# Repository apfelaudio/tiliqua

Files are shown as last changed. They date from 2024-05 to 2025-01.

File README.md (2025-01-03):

# Tiliqua

<sup>WARN: 🚧 under construction! 🚧 - this module is in active development</sup>

**Tiliqua is a powerful, open hardware FPGA-based audio multitool for Eurorack.**

For updates, join the [matrix chatroom](https://matrix.to/#/#apfaudio:matrix.org), subscribe to the [Crowd Supply page](https://www.crowdsupply.com/apfaudio/tiliqua) or my own [mailing list](https://apf.audio/)

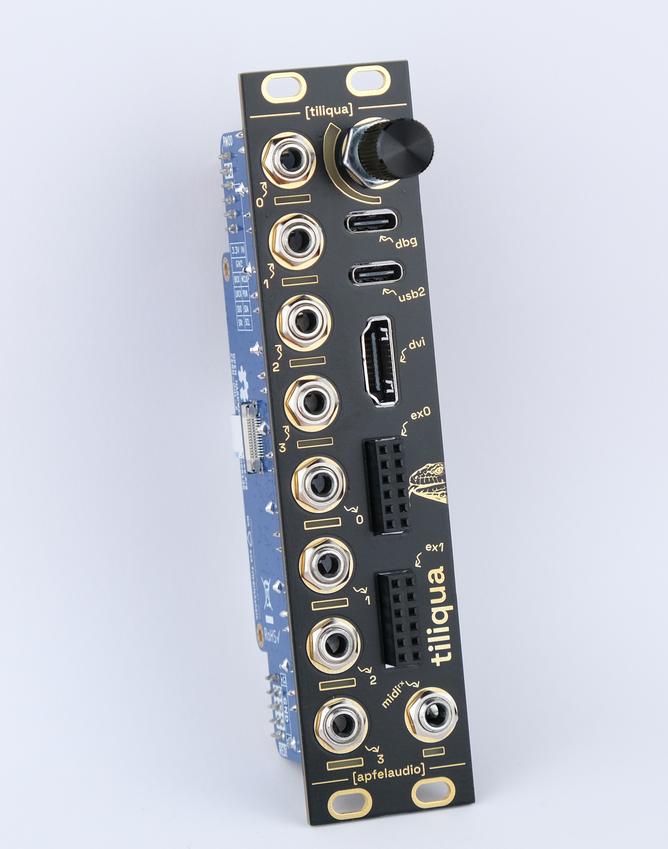
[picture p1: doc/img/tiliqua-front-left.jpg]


# Documentation

Available at [apfaudio.github.io/tiliqua](https://apfaudio.github.io/tiliqua/) (🚧 under construction)

Documentation is built from source in `gateware/docs`.

# Community

`apfaudio` has a Matrix channel, [#apfaudio:matrix.org](https://matrix.to/#/#apfaudio:matrix.org). Feel free to join to ask questions or discuss ongoing development.

Participants in this project are expected to adhere to the [Berlin Code of Conduct](https://berlincodeofconduct.org/).

## Builds on the following (awesome) open projects

- The [Amaranth HDL](https://github.com/amaranth-lang/amaranth) and [Amaranth SoC](https://github.com/amaranth-lang/amaranth-soc) projects.
- Audio interface and gateware from my existing [eurorack-pmod](https://github.com/apfaudio/eurorack-pmod) project.
- USB interface and gateware based on [LUNA and Cynthion](https://github.com/greatscottgadgets/luna/) projects.
- USB Audio gateware and descriptors based on [adat-usb2-audio-interface](https://github.com/hansfbaier/adat-usb2-audio-interface).
- Some gateware is also inherited from the [Glasgow](https://github.com/GlasgowEmbedded/glasgow) project.

# License

The hardware and gateware in this project is largely covered under the CERN Open-Hardware License V2 CERN-OHL-S, mirrored in the LICENSE text in this repository. Some gateware and software is covered under the BSD 3-clause license - check the header of the individual source files for specifics.

**Copyright (C) 2024 Sebastian Holzapfel**

The above LICENSE and copyright notice do NOT apply to imported artifacts in this repository (i.e datasheets, third-party footprints), or dependencies released under a different (but compatible) open-source license.

# Derivative works

As an addendum to the above license: if you create or manufacture your own derivative hardware, the name `apf.audio`, the names of any `apf.audio` products and the names of the authors, are *not to be used in derivative hardware or marketing materials*, except where obligated for attribution and for retaining the above copyright notice.

For example, your 3U adaptation of "apf.audio Tiliqua" could be called "Gizzard Modular - Lizardbobulator".

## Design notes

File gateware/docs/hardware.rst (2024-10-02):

Hardware overview
#################

Front
-----

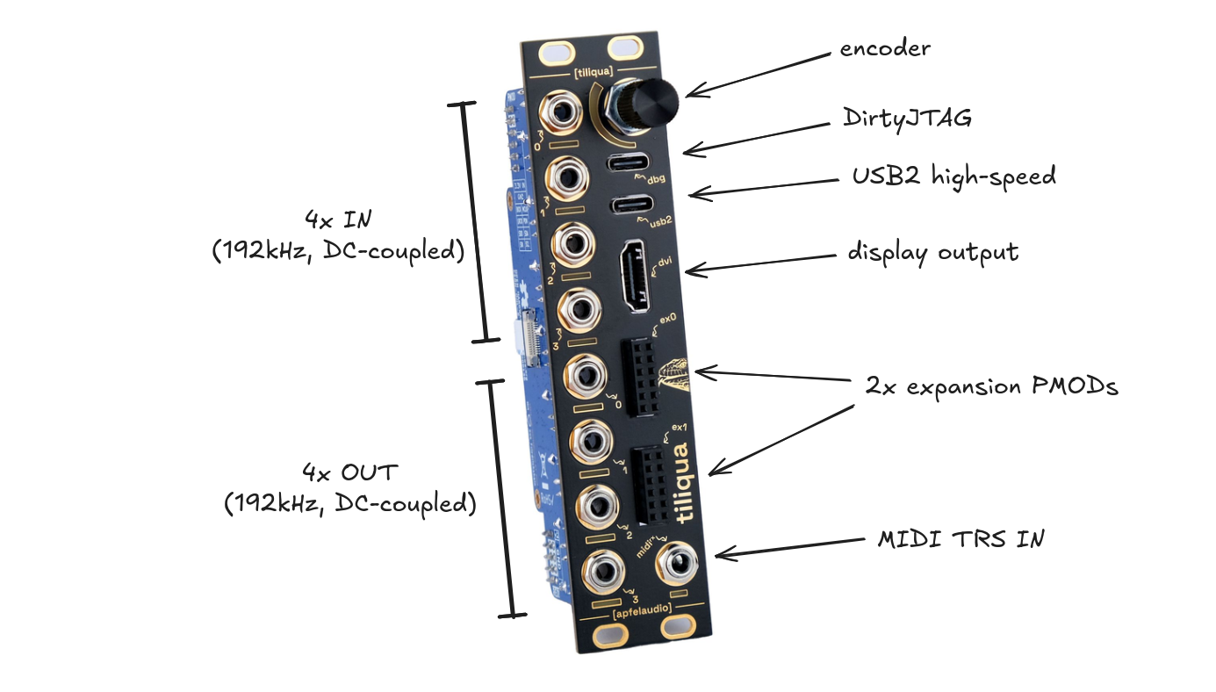
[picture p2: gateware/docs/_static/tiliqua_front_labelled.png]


Back
----

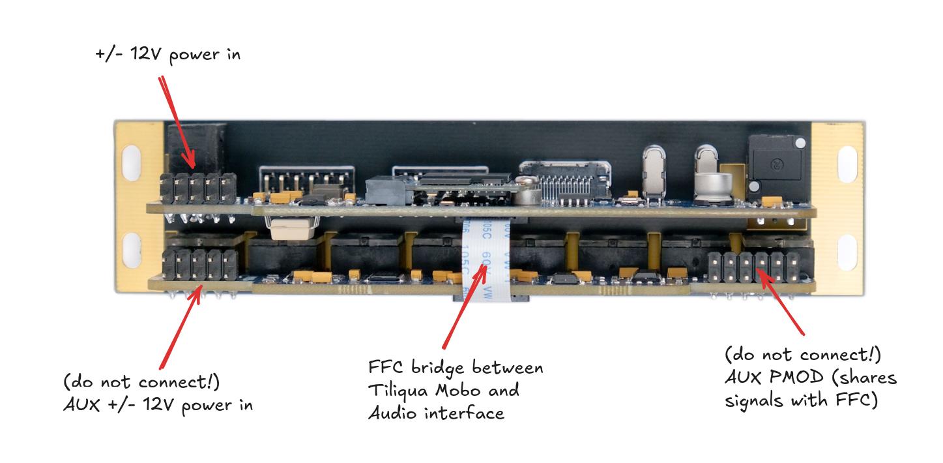
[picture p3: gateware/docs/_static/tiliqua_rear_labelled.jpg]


Power ingress
-------------

.. warning::

    Tiliqua uses an ordinary 10-pin power cable for +/- 12V ingress. You will notice however, that there are 2 such connectors on the module. **Only ONE of these should be connected**:

    - Use the 10-pin power ingress on the Tiliqua Motherboard, not the Audio Interface Board. Technically both will work, but only the former is fused (on beta R2 units).
    - Both connectors on the audio interface board (eurorack-pmod) should remain unconnected.
    - Make sure the red stripe on the IDC cable is aligned with the RED marker on the PCB.

Debug USB port
--------------

For flashing bitstreams, usually you want to be connected to the dbg USB port. This is directly connected to the on-board RP2040 which is flashed with dirtyJtag, such that you can flash bitstreams using openFPGALoader.

Audio jacks
-----------

Particularly for bitstreams with touch sensing, ensure all jacks are disconnected when the tiliqua is powered on. This is because the capacitive sensing is calibrated when the system boots. In the future I'll change this to happen every time something is dis/re-connected.

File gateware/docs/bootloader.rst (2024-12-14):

Bootloader
##########

.. note::

    'Bootloader' is a bit of a misnomer, as what is currently implemented is more like a 'bitstream selector' (although a true USB bootloader is something in the works).

Interface
---------

The bitstream selector allows you to arbitrarily select from one of 8 bitstreams after the Tiliqua powers on, without needing to connect a computer.

Put simply:

- When tiliqua boots, you can select a bitstream with the encoder (either using the display output, or by reading the currently lit LED if no display is connected).
- When you select a bitstream (press encoder), the FPGA reconfigures itself and enters the selected bitstream.
- From the new bitstream, you can always go back to the bitstream selector by holding the encoder for 3sec (this is built into the logic of every bitstream).

.. warning::

    The bitstream selector will not reboot correctly if you have
    the :py:`dbg` USB port connected. The assumption is you're flashing
    development bitstreams to SRAM in that scenario anyway.

Setup and implementation
------------------------

The bitstream selector consists of 2 key components that work together:

- The RP2040 firmware (`apfelbug - fork of dirtyJTAG <https://github.com/apfaudio/apfelbug>`_)
- The `bootloader <https://github.com/apfaudio/tiliqua/tree/main/gateware/src/top/bootloader>`_ top-level bitstream.

The difficulty here is that the ECP5 multiboot mechanism only supports rebooting from one bitstream to a single fixed new address :code:`bootaddr`, which is not sufficient for arbitrary bitstream selection. It would in theory have been possible to set up a 'bitstream chain', however that would require all bitstreams to be correctly flashed with the correct addresses at all times, which is not ideal for development. So, the solution here is more complicated, but hopefully more robust to 'less trustworthy' bitstreams.

First-time setup
^^^^^^^^^^^^^^^^

- Build and flash the `apfelbug <https://github.com/apfaudio/apfelbug>`_ project to the RP2040 (hold RP2040 BOOTSEL during power on, copy the :code:`build/*.uf2` to the usb storage device and reset)
- On the Tiliqua ECP5 SPI flash:
    - Using :code:`openFPGALoader -c dirtyJtag <bitstream> -f o <offset>`
    - flash :code:`bootloader` bitstream to offset 0x0
    - flash user bitstreams to 0x100000, 0x200000, 0x300000 ... and so on (1MB spacing)
- DISCONNECT USB DBG port, reboot Tiliqua
    - Currently :code:`apfelbug` only works correctly with the DBG connector DISCONNECTED or with the UART port open on Linux and CONNECTED. Do not have the USB DBG connected without the UART0 open with :code:`picocom` or so.
- Now when Tiliqua boots you will enter the bootloader. Use the encoder to select an image. Hold the encoder for >3sec in any image to go back to the bootloader.

Bitstream Manifest
^^^^^^^^^^^^^^^^^^

By default the bootloader screen will report all bitstream names as :code:`<unknown>`. The :code:`bootloader` bitstream can optionally read from a JSON manifest stored at the end of SPI flash called a 'Bitstream Manifest'. Such a :code:`manifest.json` file can be copied from :code:`gateware/src/top/bootloader/fw/example-manifest.json`. You can flash this to the end of the SPI flash so the bootloader knows what each bitstream should be called.

.. code-block:: bash

    sudo openFPGALoader -c dirtyJtag -f -o 0xfff000 --file-type raw manifest.json

Note: this address :code:`0xfff000` comes from :code:`src/tiliqua/tiliqua_soc.py`.

Assuming the bootloader bitstream is correctly already flashed to 0x0, this command will also reset the FPGA, re-enter the bootloader, and display the updated bitstream manifest.

At the moment, the bootloader itself does no verification that there are actually bitstreams flashed to each slot corresponding to the names. If a bitstream is not actually in a designated slot or is corrupt, selecting the bad slot will simply reboot the FPGA and re-enter the bootloader.

ECP5 implementation
^^^^^^^^^^^^^^^^^^^

The ECP5 :code:`bootloader` bitstream does nothing except tell the RP2040 that it wants to be rebooted into a new bitstream (over UART). However, the user bitstreams are responsible for asserting PROGRAMN when the encoder is held, to reconfigure back to the bootloader bitstream.

RP2040 implementation
^^^^^^^^^^^^^^^^^^^^^

:code:`apfelbug` firmware includes the same features as :code:`pico-dirtyjtag` (USB-JTAG and USB-UART bridge), with some additions:

- UART traffic is inspected to look for keywords.
- If a keyword is encountered e.g. :code:`BITSTREAM1`, a pre-recorded JTAG stream stored on the RP2040's SPI flash is decompressed and replayed. The JTAG streams are instances of the `bootstub <https://github.com/apfaudio/tiliqua/blob/main/gateware/src/top/bootstub/top.py>`_ top-level bitstream. These are tiny bitstreams that are programmed directly into SRAM with the target :code:`bootaddr` and PROGRAMN assertion.
- This facilitates ECP5 multiboot (jumping to arbitrary bitstreams) without needing to write to the ECP5's SPI flash and exhausting write cycles.

Recording new JTAG streams for RP2040
^^^^^^^^^^^^^^^^^^^^^^^^^^^^^^^^^^^^^

TODO documentation, not necessary to change this for any ordinary usecase. Update this if needed for SoldierCrab R3.

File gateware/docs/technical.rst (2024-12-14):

Hardware details
################

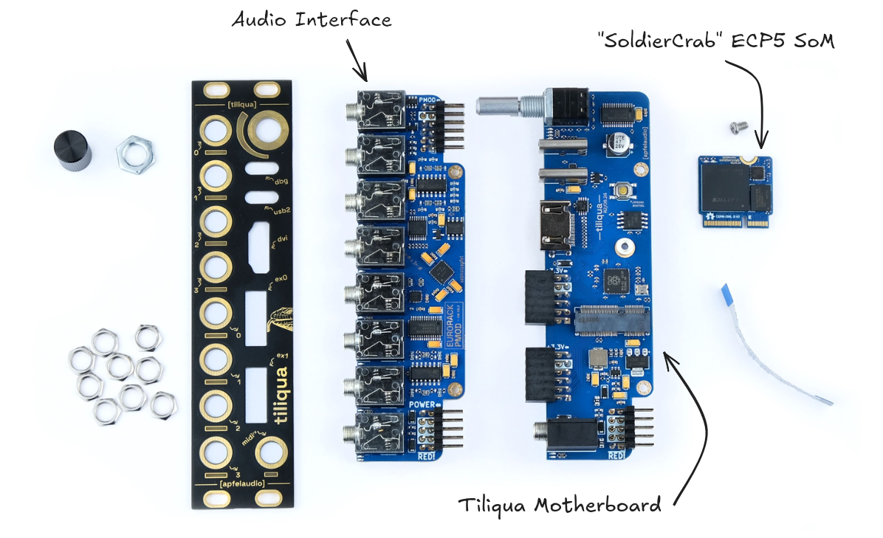
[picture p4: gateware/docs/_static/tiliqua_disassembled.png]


Audio Interface
---------------

**KiCAD files + schematics here:** `eurorack-pmod R3.3 hardware <https://github.com/apfaudio/eurorack-pmod/tree/master/hardware/schematics>`_

- 8 (4 in + 4 out) DC-coupled audio channels, 192 KHz / 24-bit sampling supported
- Touch and proximity sensing on all 8 audio jacks (if unused)
- PWM-controlled, user-programmable red/green LEDs on each audio channel
- Jack insertion detection on all 8 jacks

Motherboard
-----------

**KiCAD files + schematics here:** `Tiliqua R2 motherboard <https://github.com/apfaudio/tiliqua/tree/main/hardware>`_

- Switched rotary encoder with bar graph display.
- Dual USB ports:
    - `dbg`: Included RP2040-based JTAG debugger supported by `openFPGAloader`
    - `usb2`: USB PHY connected directly to FPGA for high-speed USB Audio support
- Display output for video synthesis (maximum resolution 720/60P)
- 2x expansion ports for up to 24 simultaneous audio channels (PMOD-compatible)
- MIDI-In jack (TRS-A standard)

Embedded FPGA SoM (`soldiercrab`)
---------------------------------

**Schematics here :** `SoldierCrab R2 <https://github.com/apfaudio/tiliqua/tree/main/hardware/schematics>`_

.. note::

    SoldierCrab KiCAD files need some cleanup and will be published before the
    CrowdSupply campaign is launched.

- Lattice ECP5 (25 K) FPGA, supported by open-source FPGA toolchains
- 256 Mbit (32 MByte) HyperRAM / oSPI RAM (for long audio buffers or video framebuffers)
- 128 Mbit (16 MByte) SPI flash for user bitstreams
- High-speed USB HS PHY (ULPI)

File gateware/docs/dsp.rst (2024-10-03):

Tiliqua DSP Library
###################

Overview
--------

TODO short overview of the DSP library philosophy.

TODO link to Amaranth documentation on streams.

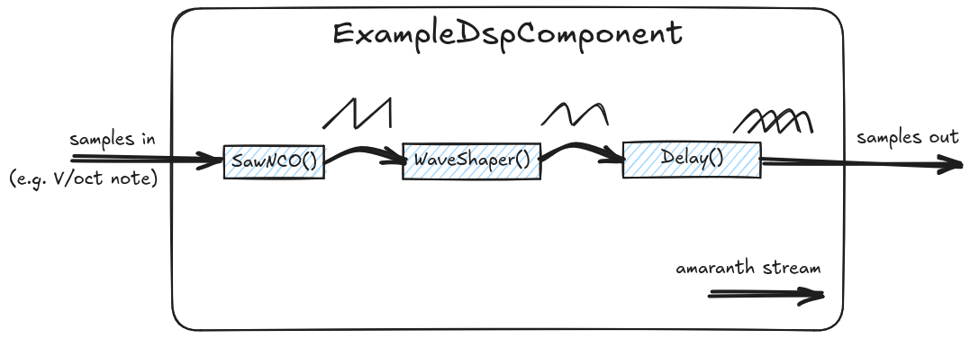
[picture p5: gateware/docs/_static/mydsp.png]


Delay Lines
-----------

.. autoclass:: tiliqua.delay_line.DelayLine
.. autoclass:: tiliqua.delay_line.DelayLineTap

Filters
-------

.. autoclass:: tiliqua.dsp.SVF
.. autoclass:: tiliqua.dsp.FIR
.. autoclass:: tiliqua.dsp.Boxcar

Oscillators
-----------

.. autoclass:: tiliqua.dsp.SawNCO

Effects
-------

.. autoclass:: tiliqua.dsp.WaveShaper
.. autoclass:: tiliqua.dsp.PitchShift

VCAs
----

.. autoclass:: tiliqua.dsp.VCA
.. autoclass:: tiliqua.dsp.GainVCA

Mixing
------

.. autoclass:: tiliqua.dsp.MatrixMix

Resampling
----------

.. autoclass:: tiliqua.dsp.Resample

One-shot
--------

.. autoclass:: tiliqua.dsp.Trigger
.. autoclass:: tiliqua.dsp.Ramp

Stream utilities
----------------

Splitting / merging streams
^^^^^^^^^^^^^^^^^^^^^^^^^^^

.. autoclass:: tiliqua.dsp.Split
.. autoclass:: tiliqua.dsp.Merge

Connecting and remapping streams
^^^^^^^^^^^^^^^^^^^^^^^^^^^^^^^^
.. autofunction:: tiliqua.dsp.connect_remap
.. autofunction:: tiliqua.dsp.channel_remap

Connecting streams in feedback loops
^^^^^^^^^^^^^^^^^^^^^^^^^^^^^^^^^^^^

.. autoclass:: tiliqua.dsp.KickFeedback
.. autofunction:: tiliqua.dsp.connect_feedback_kick

Other utilities
---------------

.. autofunction:: tiliqua.dsp.named_submodules

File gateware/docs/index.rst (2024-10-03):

Tiliqua Manual
##############

.. warning::

   This manual is under construction and very incomplete!



.. toctree::
   :maxdepth: 2

   hardware
   technical
   install
   gettingstarted
   soc
   bootloader
   top
   dsp

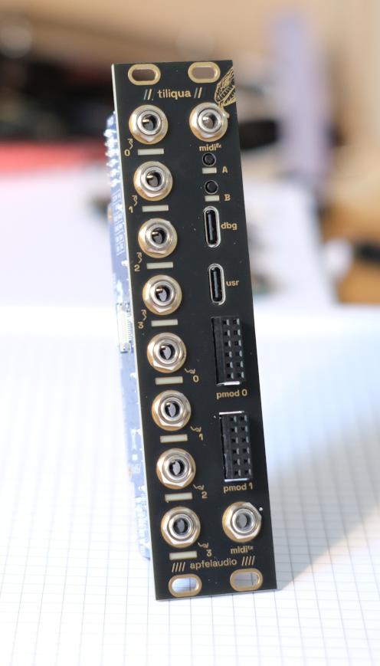
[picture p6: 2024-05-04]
doc/img/tiliqua-proto1-front.jpg

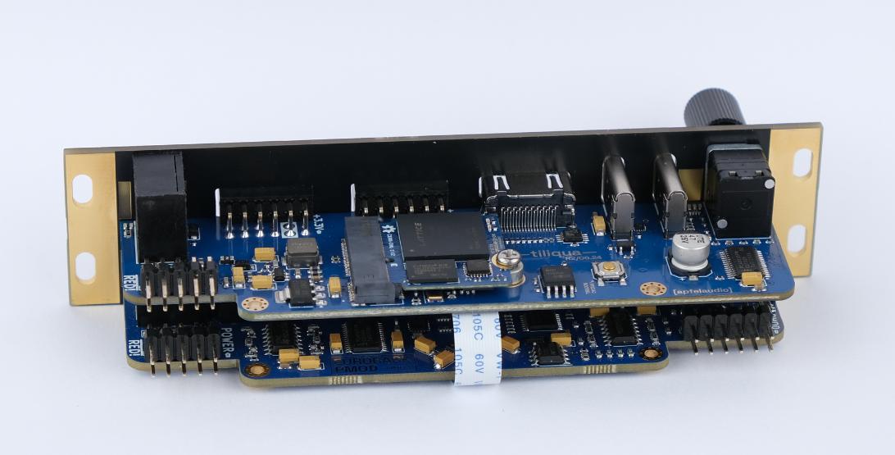
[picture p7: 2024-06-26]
doc/img/tiliqua-rear-left.jpg

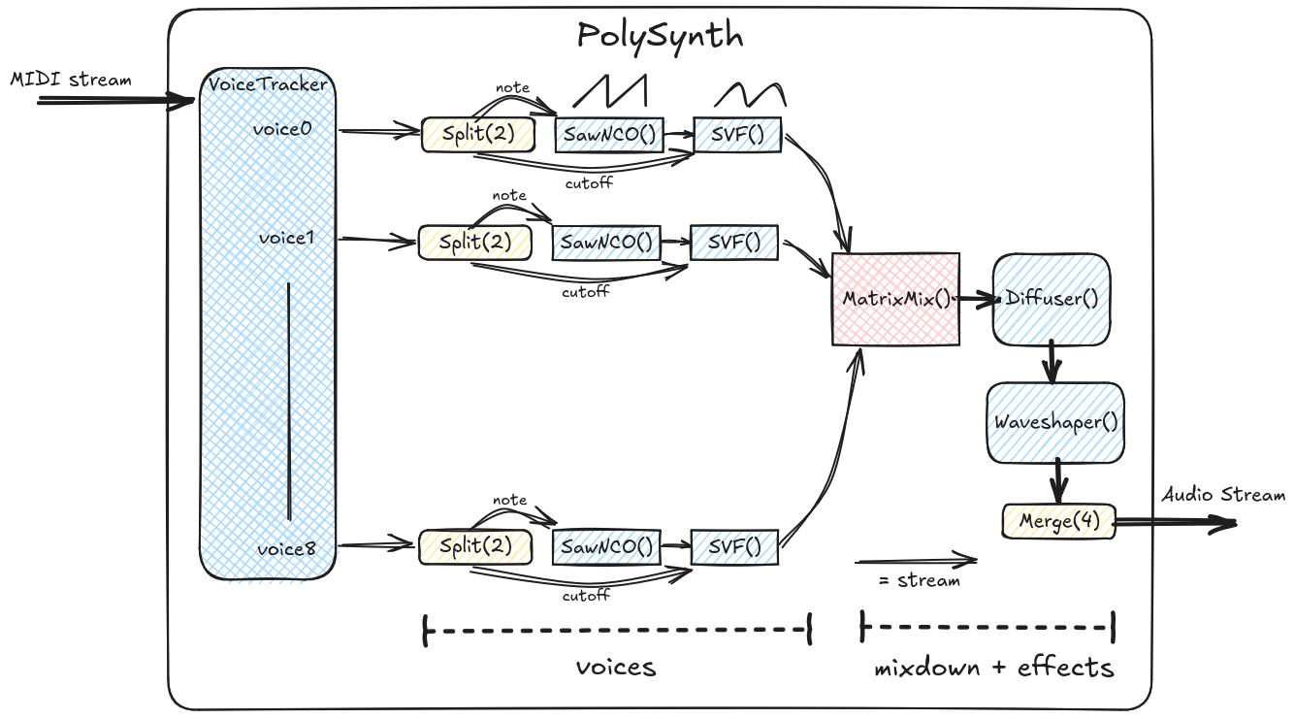
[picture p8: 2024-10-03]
gateware/docs/_static/polysynth.png

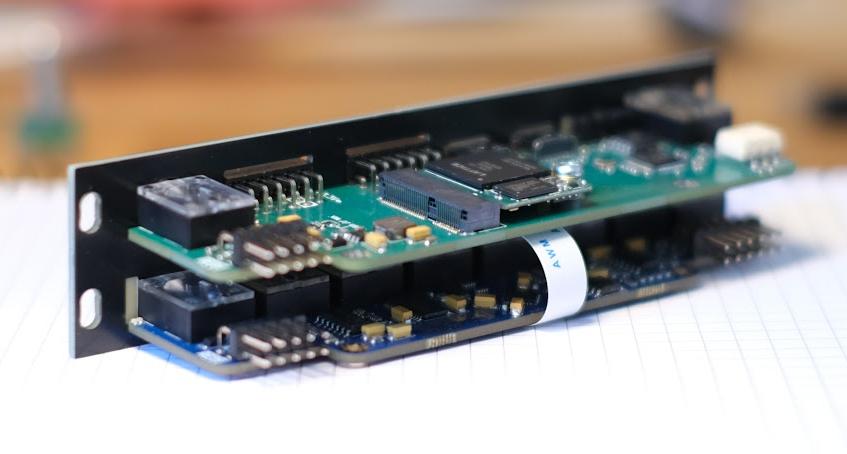
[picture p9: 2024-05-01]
doc/img/tiliqua-proto1-back.jpg

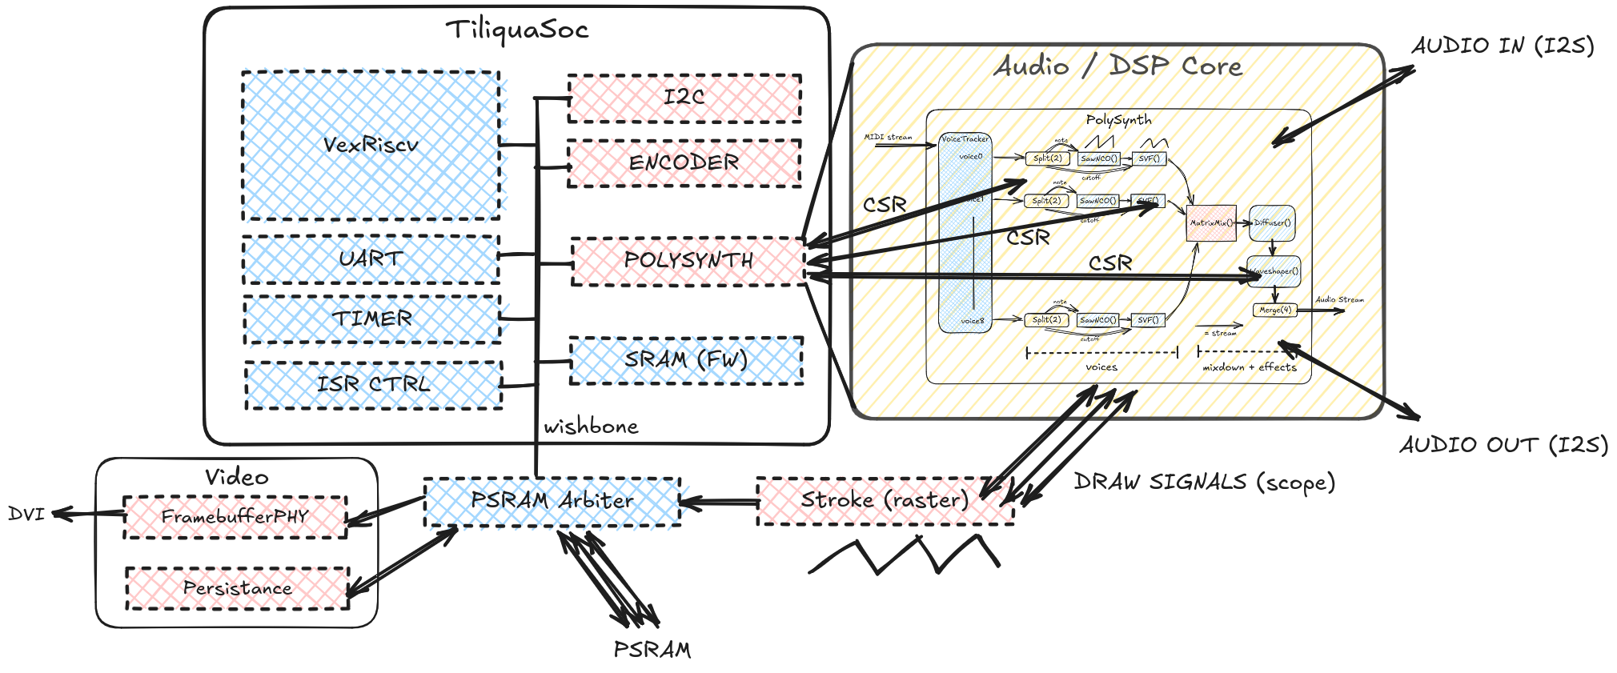
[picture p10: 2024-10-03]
gateware/docs/_static/tiliquasoc.png

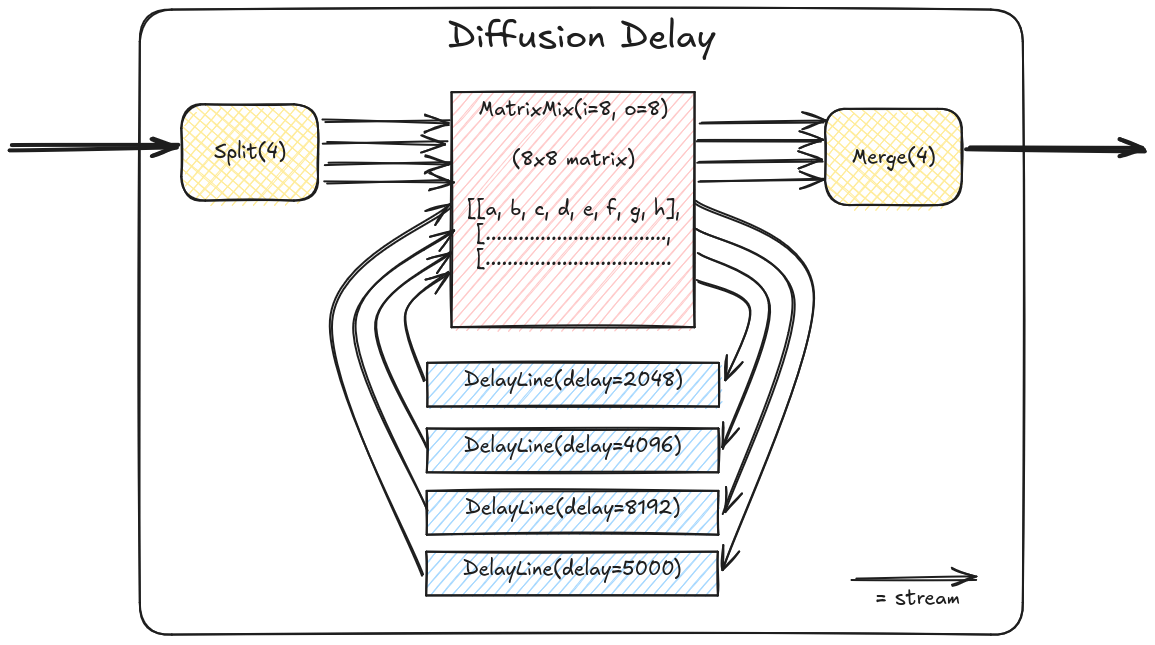
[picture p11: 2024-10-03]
gateware/docs/_static/diffusor.png

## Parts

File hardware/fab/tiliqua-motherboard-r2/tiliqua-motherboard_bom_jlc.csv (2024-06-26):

Comment | Designator | Footprint | LCSC Part #
0.1uF | C1,C2,C3,C4,C5,C6,C7,C8,C9,C10,C13,C14 | C_0402_1005Metric | C307331
2.2uF | C11,C12 | C_0402_1005Metric | C12530
18pF/50V/5%/C0G/C0402 | C15,C16 | C_0402_1005Metric | C1549
22.0uF | C23,C26 | CP_EIA-3216-10_Kemet-I | C782264
100nF | C25,C28,C30,C34,C43,C27 | C_0603_1608Metric | C14663
22uF | C29,C32,C38,C42 | CP_EIA-3216-10_Kemet-I | C782264
100pF | C31 | C_0603_1608Metric | C14858
47uF | C33 | CP_Elec_6.3x5.4 | C88735
10n | C39,C40,C41 | C_0402_1005Metric | C60133
1N4007FL | D1,D2,D3 | D_SOD-123F | C493190
3V6 | D4 | D_SOD-123 | C173412
LED 0402 GREEN | D5,D6,D7,D8,D13,D14,D15,D16 | LED_0402_1005Metric | C2856703
LED 0402 RED | D9,D10,D11,D12,D17,D18,D19,D20 | LED_0402_1005Metric | C965790
15V 200mA | F1,F2 | Fuse_0805_2012Metric | C883103
Conn_01x15 | J1 | FFC_0.5-14P_CTXJ-H2.0_1 | C5378715
Conn_02x06_Top_Bottom | J2,J3 | PinSocket_2x06_P2.54mm_Horizontal | C2897426
~ | J4 | AUDIO-TH_PJ-325M | C2884942
USB_C_Receptacle_USB2.0_14P | J5,J7 | USB-C-TH_U264-141N-4BAC10 | C692526
CONN 2x5 P=2.54mm | J6 | PinHeader_2x05_P2.54mm_Horizontal | C492433
MICROMOD-2222 | J8 | TE_21992304 | C2977809
DVI_GPDI | J10 | HDMI_A_Amphenol_10029449-x01xLF_Horizontal | C428493
FERRITE | L1,L2,L4,L5,L6,L7 | L_0603_1608Metric | C14709
10uH 2A | L3 | L_Vishay_IHLP-2020 | C844996
4K7 | R1,R2,R9,R25,R32 | R_0402_1005Metric | C25900
10K | R3,R4,R23,R13,R14,R21,R22,R29,R30,R27,R33 | R_0402_1005Metric | C25744
100R | R5,R8 | R_0402_1005Metric | C25076
27R | R6,R7 | R_0402_1005Metric | C138021
220R | R10,R16 | R_0402_1005Metric | C25091
5.1K | R11,R12 | R_0402_1005Metric | C25905
1K | R15 | R_0402_1005Metric | C11702
157K (158K) | R17 | R_0402_1005Metric | C861679
30K | R18 | R_0402_1005Metric | C25776
900K (910K) | R20 | R_0402_1005Metric | C25800
18K | R24 | R_0402_1005Metric | C138044
549 | R31 | R_0402_1005Metric | C474081
270 | R34,R35,R36,R37,R38,R39,R40,R41 | R_0402_1005Metric | C25099
120R | RN1,RN2,RN3,RN4 | R_Array_Convex_4x0402 | C326871
SW_Tactile_SPST | SW2 | SW_SPST_SKQG_WithStem | C202424
ZD25WQ16CSIGT(SOIC-8_208mils) | U1 | SOIC-8W_5.3x5.3mm_P1.27mm | C5353597
RP2040(QFN-56_7x7mm_P0.4mm) | U2 | QFN-56-1EP_7x7mm_P0.4mm_EP3.2x3.2mm_ThermalVias | C2040
PCA9306DP | U3 | TSSOP-8_3x3mm_P0.65mm | C128835
H11L1SR2M | U4 | DIP-6_W8.89mm_SMDSocket_LongPads | C20082
AP63200WU | U5 | TSOT-23-6 | C2071868
AMS1117-3.3 | U6 | SOT-223-3_TabPin2 | C347222
PCA9635 LED DRIVER | U7 | TSSOP-28_4.4x9.7mm_P0.65mm | C110795
TUSB322I | U8 | Texas_X2QFN-12_1.6x1.6mm_P0.4mm | C2674422
AP2161W | U9 | SOT-23-5 | C176957
Crystal_GND24_Small | Y1 | Crystal_SMD_3225-4Pin_3.2x2.5mm | C133334

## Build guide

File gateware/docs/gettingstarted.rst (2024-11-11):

Getting started
###############

Building example projects
-------------------------

Each top-level bitstream has a command-line interface. You can see the options by running (for example):

.. code-block:: bash

   # from `gateware` directory
   pdm dsp

The available options change depending on the top-level project. For example, many projects have video output, and from the CLI you can select the video resolution.

A few examples of building top-level bitstreams:

.. code-block:: bash

   # from `gateware` directory

   # for the selftest bitstream (prints diagnostics out DVI and serial)
   pdm selftest build
   # for a vectorscope / oscilloscope
   pdm xbeam build
   # for a polyphonic MIDI synth
   pdm polysyn build
   # for the LUNA-based 4in + 4out USB soundcard example
   # note: LUNA USB port presents itself on the second USB port (not dbg)!
   pdm usb_audio build
   # for a 4-channel waveshaping oscillator
   pdm dsp build --dsp-core nco
   # for a diffusion delay effect
   pdm dsp build --dsp-core diffuser
   # simplified vectorscope (no SoC / menu system)
   pdm vectorscope_no_soc build

Generally, bitstreams are also built in CI - check ``.github/workflows`` if you need more gruesome details on how systems are built.

Flashing example projects
-------------------------

The built-in RP2040 JTAG debugger is based on the ``dirtyJtag`` project. For non-SoC projects that don't require extra firmware, you can directly flash bitstreams to the SRAM of the FPGA like so:

.. code-block:: bash

   sudo openFPGALoader -c dirtyJtag build/top.bit

When you build a project from the command line, on completion they will usually print some instructions on how to flash them. For SoC bitstreams, there may be multiple steps (e.g. bitstream and firmware, or other artifacts). You can add the :code:`--flash` option to perform these steps automatically.

.. warning::

    If you flash with to the SPI flash, usually you will want to specify
    an offset so you don't overwrite the bootloader. See the *Bootloader* section
    for more information on flash addressing. In any case it's not possible to
    brick the Tiliqua - so don't be too scared to play!

If you are running an SoC, once you have flashed all artifacts it will give you serial output that you can monitor like so:

.. code-block:: bash

   sudo picocom -b 115200 /dev/ttyACM0

Simulating DSP cores
--------------------

The easiest way to debug the internals of a DSP project is to simulate it. This project provides some shortcuts to enable simulating designs end-to-end with Verilator (at some point these will be migrated to Amaranths CXXRTL simulation backend, once it lands).

For example, to simulate the waveshaping oscillator example:

.. code-block:: bash

   # from `gateware` directory
   pdm dsp sim --dsp-core nco

In short this command:

- Elaborates your Amaranth HDL and convert it to Verilog
- Verilates your verilog into a C++ implementation, compiling it against ``sim_dsp_core.cpp`` provided in ``gateware/top/dsp`` that excites the audio inputs (you can modify this).
- Runs the verilated binary itself and spits out a trace you can view with ``gtkwave`` to see exactly what every net in the whole design is doing.

Simulating SoC cores
--------------------

A subset of SoC-based top-level projects also support end-to-end simulation (i.e including firmware co-simulation). For example, for the selftest SoC:

.. code-block:: bash

   # from `gateware` directory
   pdm selftest sim

   # ...

   run verilated binary 'build/obj_dir/Vtiliqua_soc'...
   sync domain is: 60000 KHz (16 ns/cycle)
   pixel clock is: 74250 KHz (13 ns/cycle)
   [INFO] Hello from Tiliqua selftest!
   [INFO] PSRAM memtest (this will be slow if video is also active)...
   [INFO] write speed 1687 KByte/seout frame00.bmp
   c
   [INFO] read speed 1885 KByte/sec
   [INFO] PASS: PSRAM memtest

UART traffic from the firmware is printed to the terminal, and each video frame is emitted as a bitmap. This kind of simulation is useful for debugging the integration of top-level SoC components.

Simulating vectorscope core
---------------------------

There is a top-level ``vectorscope_no_soc`` provided which is also useful for debugging integration issues between the video and memory controller cores. This can be simulated end-to-end as follows (``--trace-fst`` is also useful for saving waveform traces):

.. code-block:: bash

   # from `gateware` directory
   pdm vectorscope_no_soc sim --trace-fst

Using the ILA
-------------

Some cores support using a built-in ILA (integrated logic analyzer), to collect waveform traces on the hardware into on-FPGA block RAM, which is sampled at the system clock and dumped out the serial port.

For example:

.. code-block:: bash

   # from `gateware` directory
   pdm vectorscope_no_soc build --ila --ila-port /dev/ttyACM0

This will build the bitstream containing the ILA, flash the bitstream, then open the provided serial port waiting for an ILA dump from the Tiliqua to arrive. Once received, the dump will be saved to a waveform trace file.

.. note::
   You may have to play with permissions for flashing to work correctly - make sure ``openFPGALoader`` can run locally under your user without ``sudo``.

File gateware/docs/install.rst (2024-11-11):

Prerequisites
#############

On an Ubuntu system, the following are the main dependencies:

- The build system: install `pdm <https://github.com/pdm-project/pdm>`_
- For synthesis: install `oss-cad-suite <https://github.com/YosysHQ/oss-cad-suite-build>`_
- For examples that include a softcore: `rust <https://rustup.rs/>`_

  - To build stripped images for RISC-V, you also need:

    .. code-block:: bash

       rustup target add riscv32im-unknown-none-elf
       rustup component add rustfmt clippy llvm-tools
       cargo install cargo-binutils svd2rust form

To set up the environment:

.. code-block:: bash

   cd gateware
   git submodule update --init --recursive
   pdm install

All examples are built in CI. If you're having trouble setting up your environment, it may also be worth checking the github workflow configuration.

By default, synthesis will use :code:`yowasp-yosys` and :code:`yowasp-nextpnr-ecp5` , rather than any :code:`oss-cad-suite` you have installed. When running locally, builds are usually faster if you point to your own installation - modify :code:`gateware/.env.toolchain` (simply deleting it will try to find yosys in your PATH).

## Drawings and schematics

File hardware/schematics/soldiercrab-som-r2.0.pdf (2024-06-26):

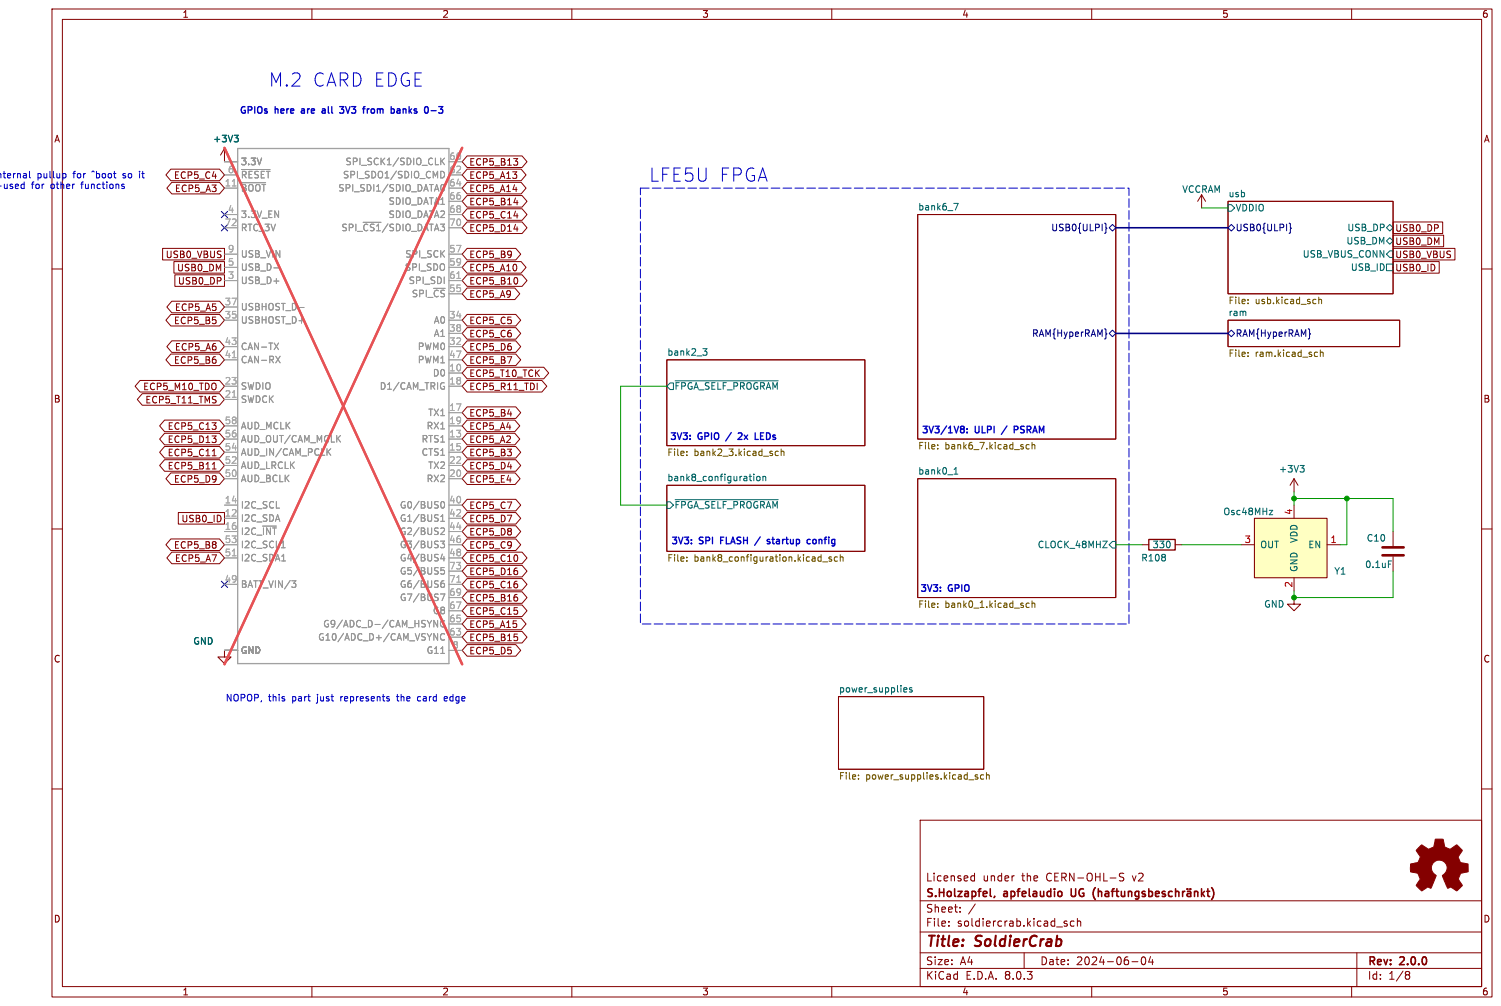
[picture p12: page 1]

3V3: SPI FLASH / startup config

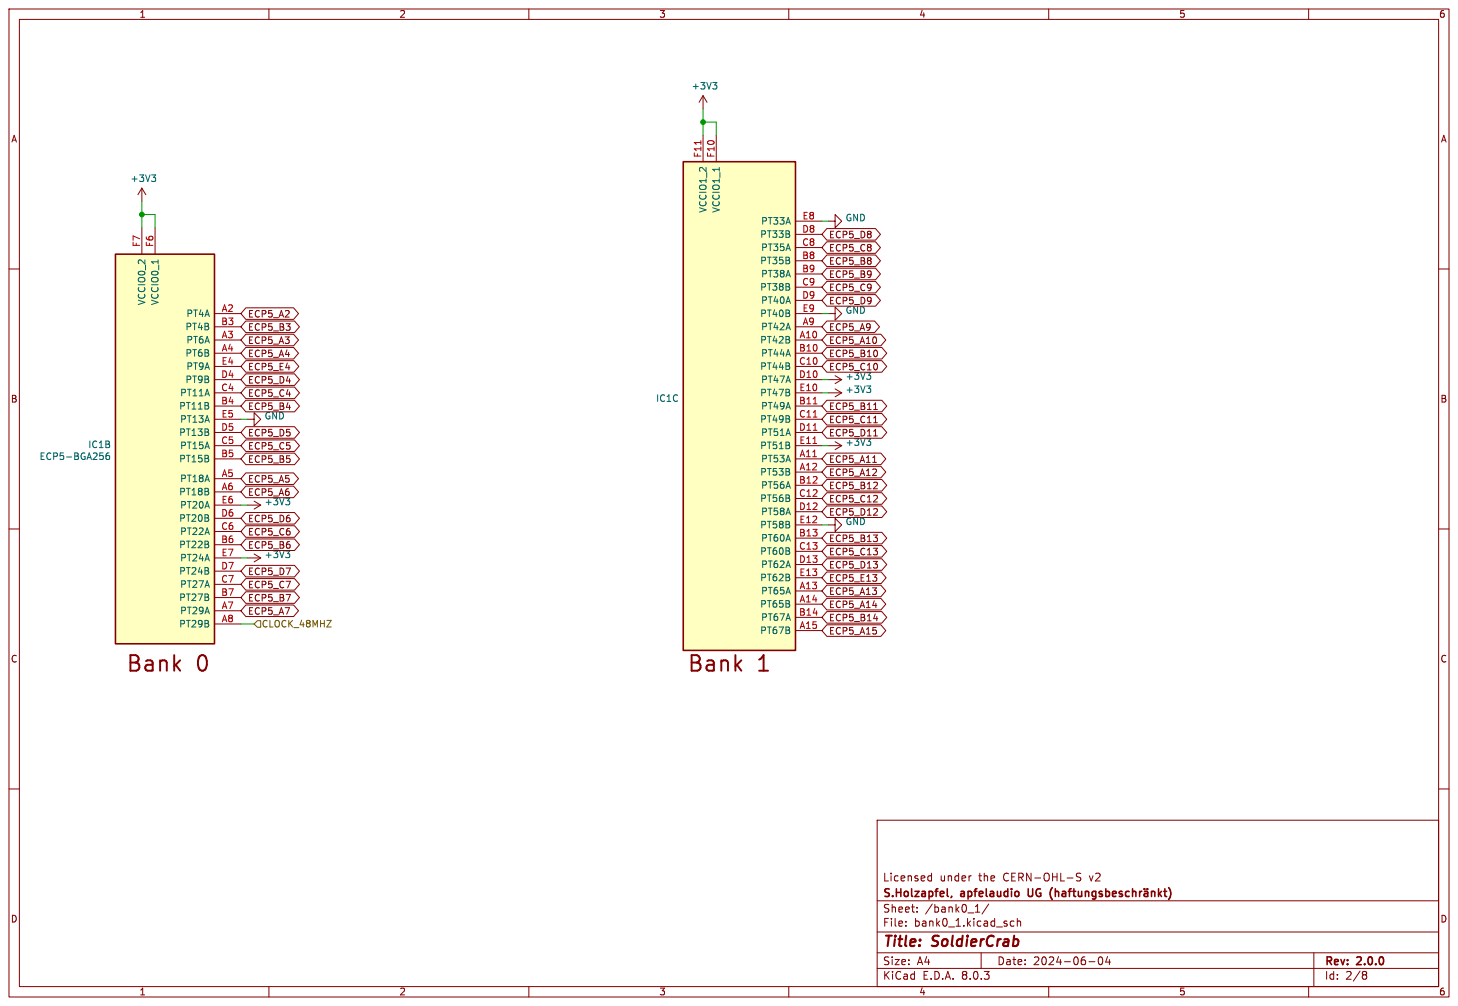
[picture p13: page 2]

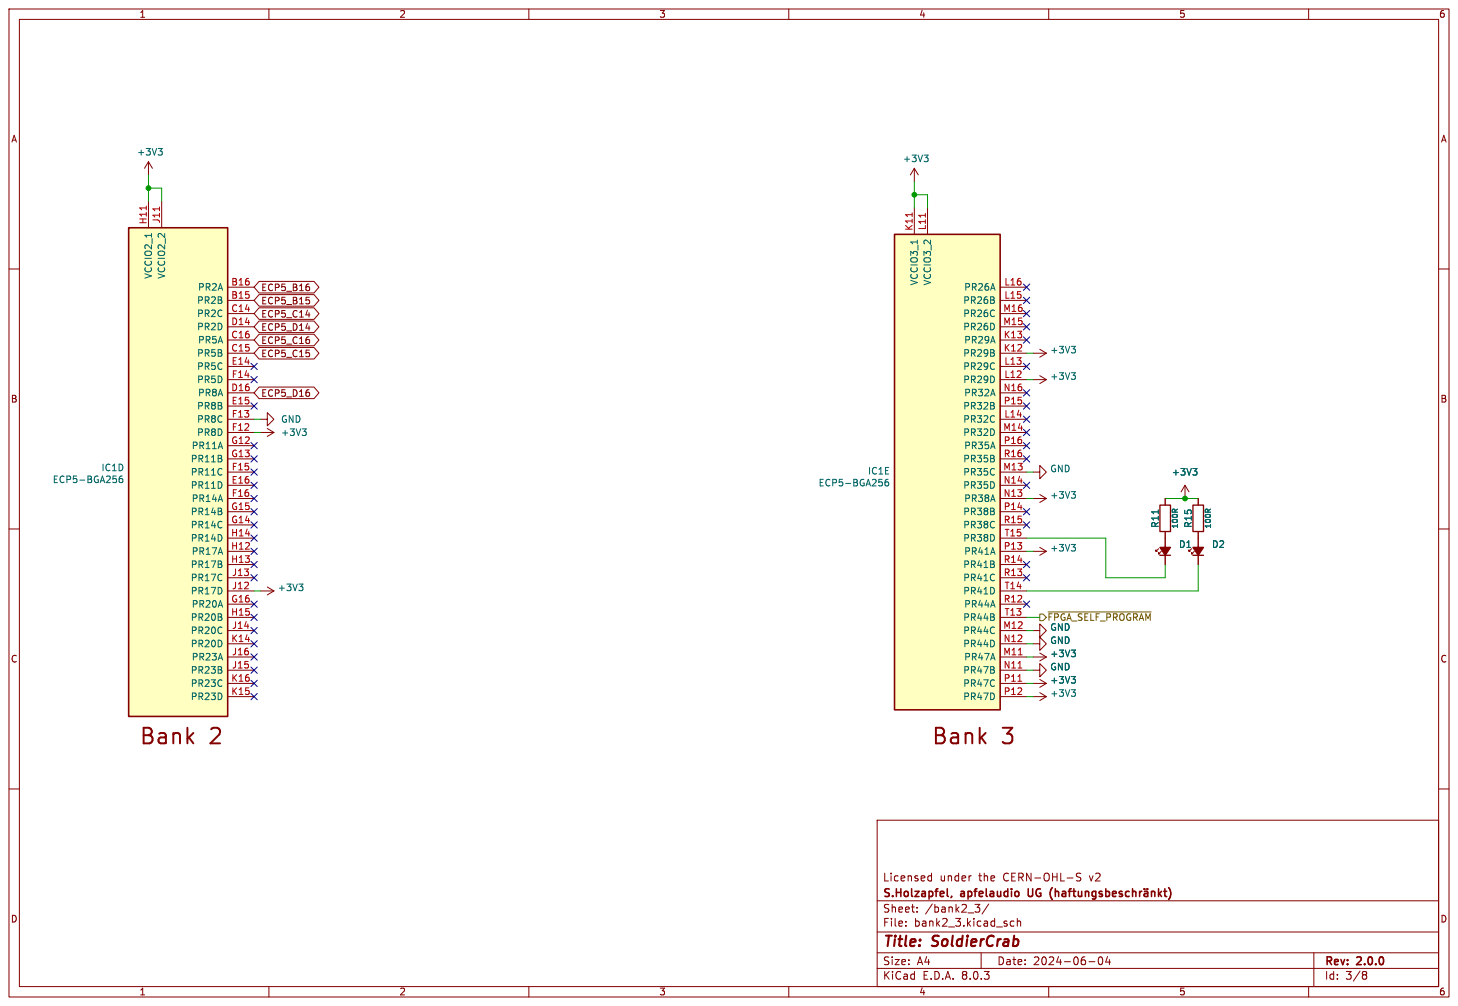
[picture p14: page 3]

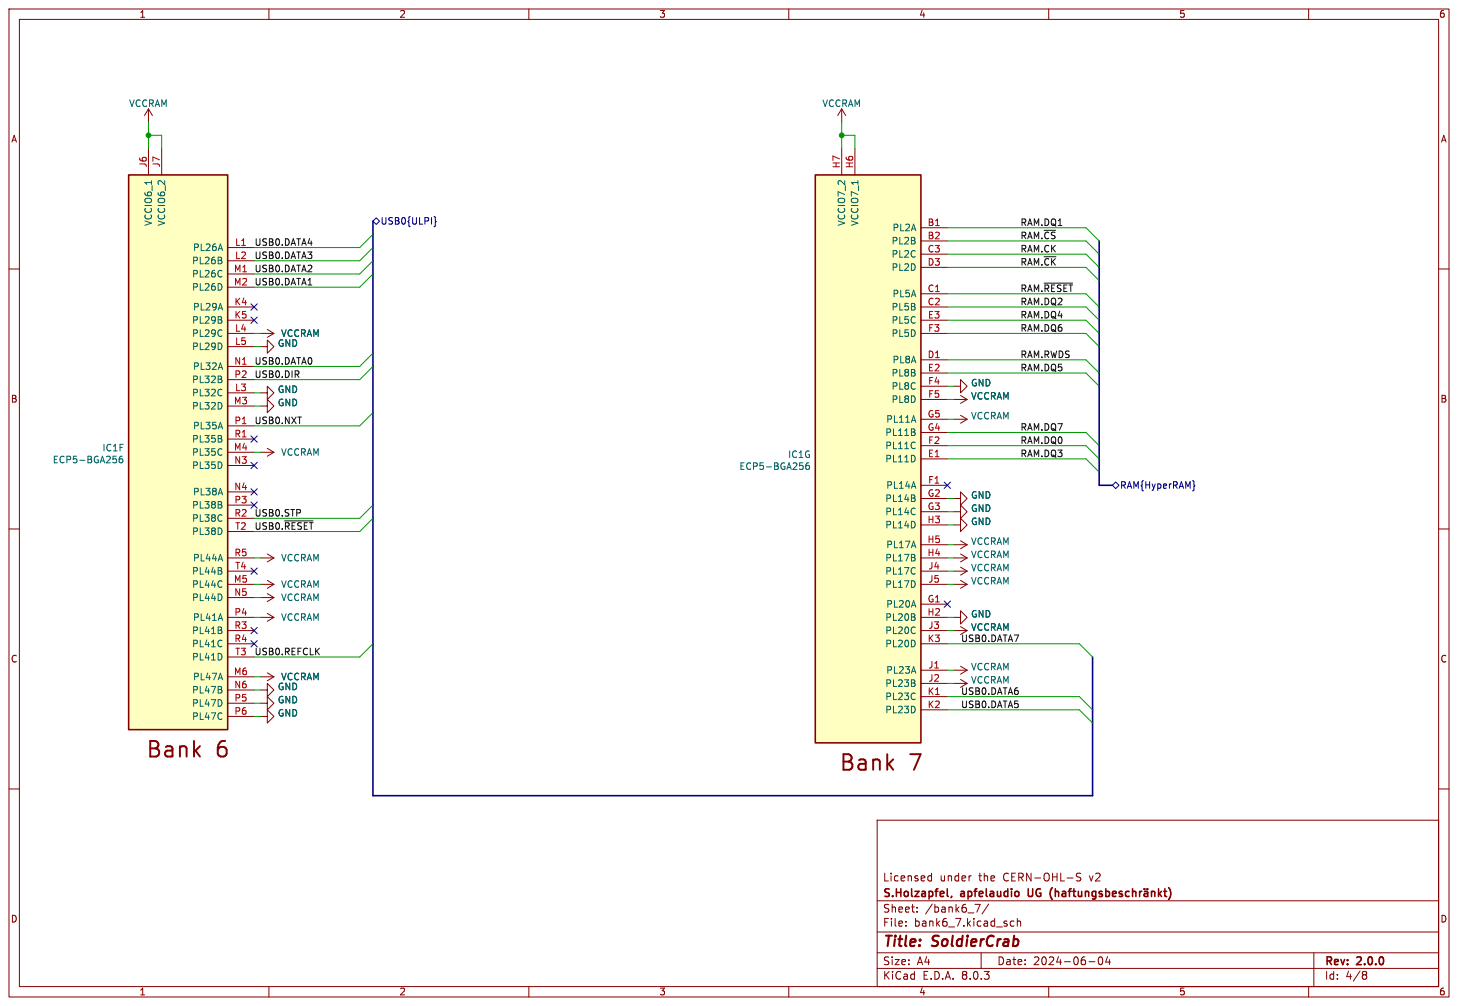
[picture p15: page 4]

RAM{HyperRAM} RAM.CK RAM.~{CK}

GND GND

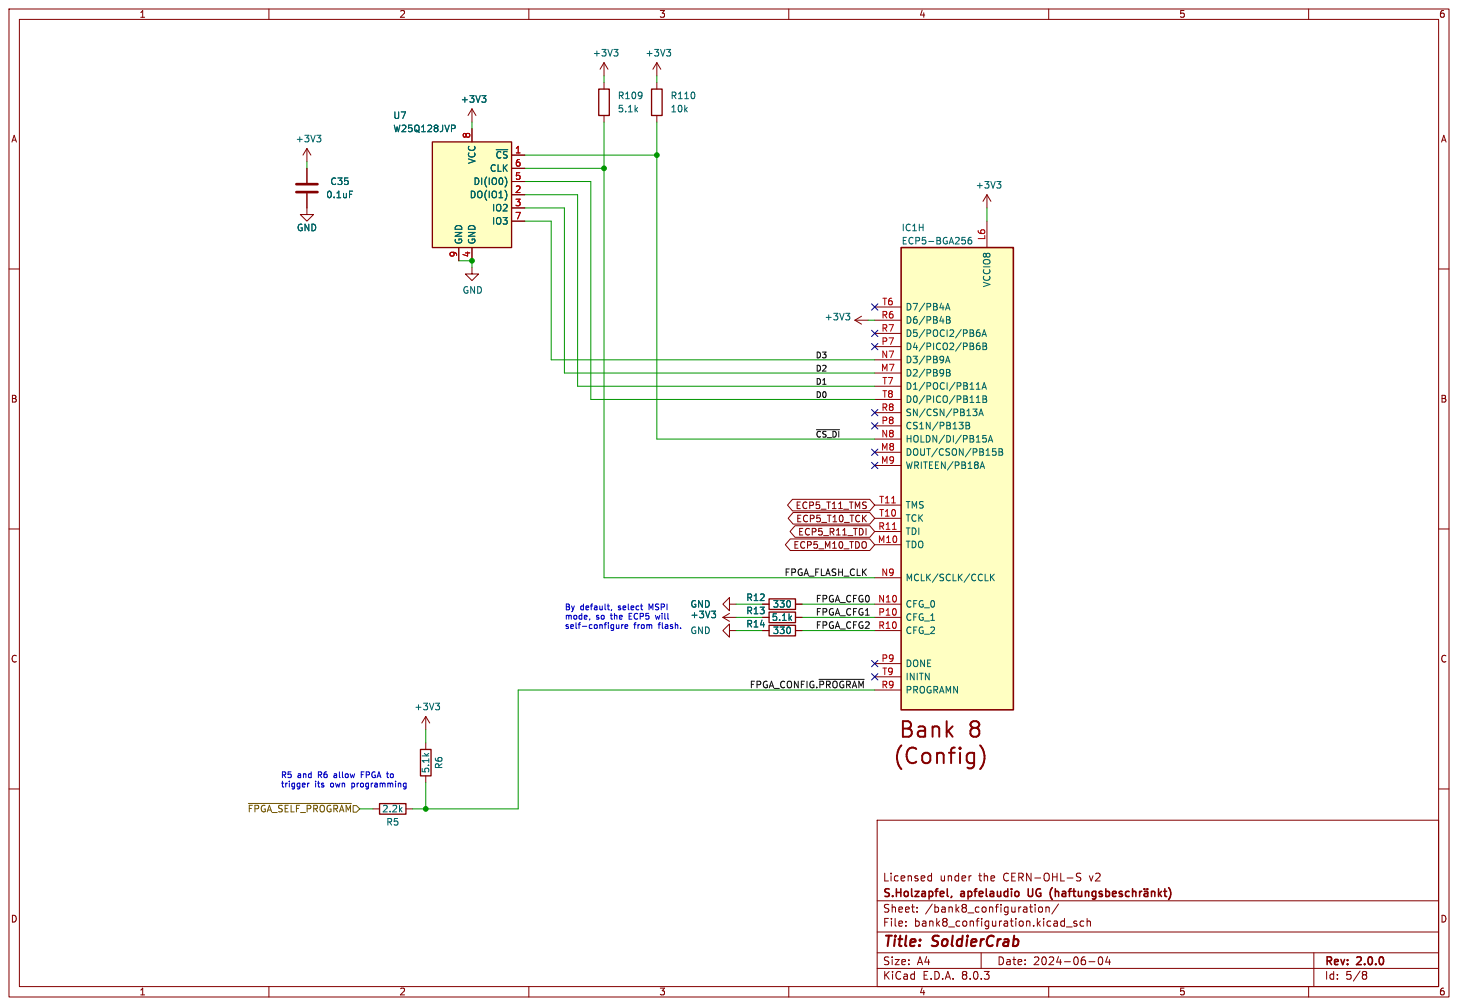
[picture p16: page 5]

~{CS_DI} D1 R5 and R6 allow FPGA to

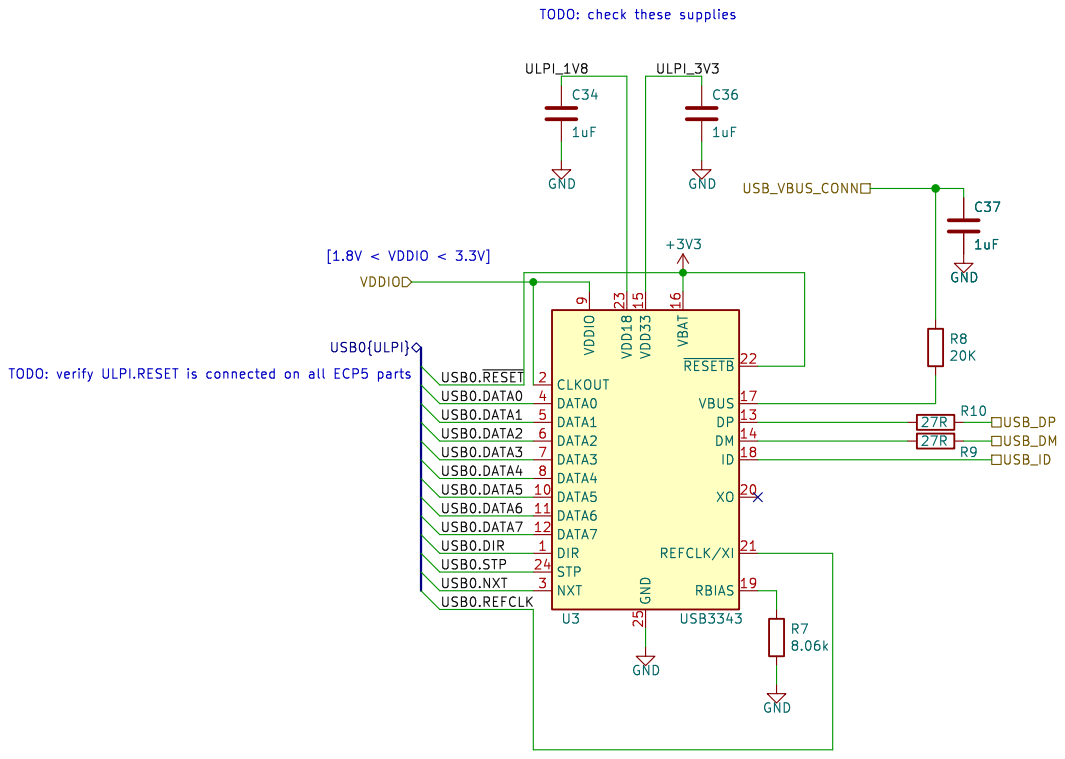
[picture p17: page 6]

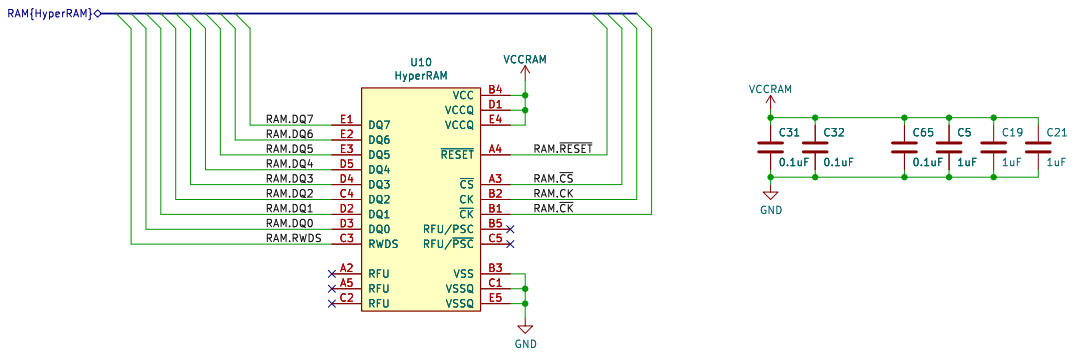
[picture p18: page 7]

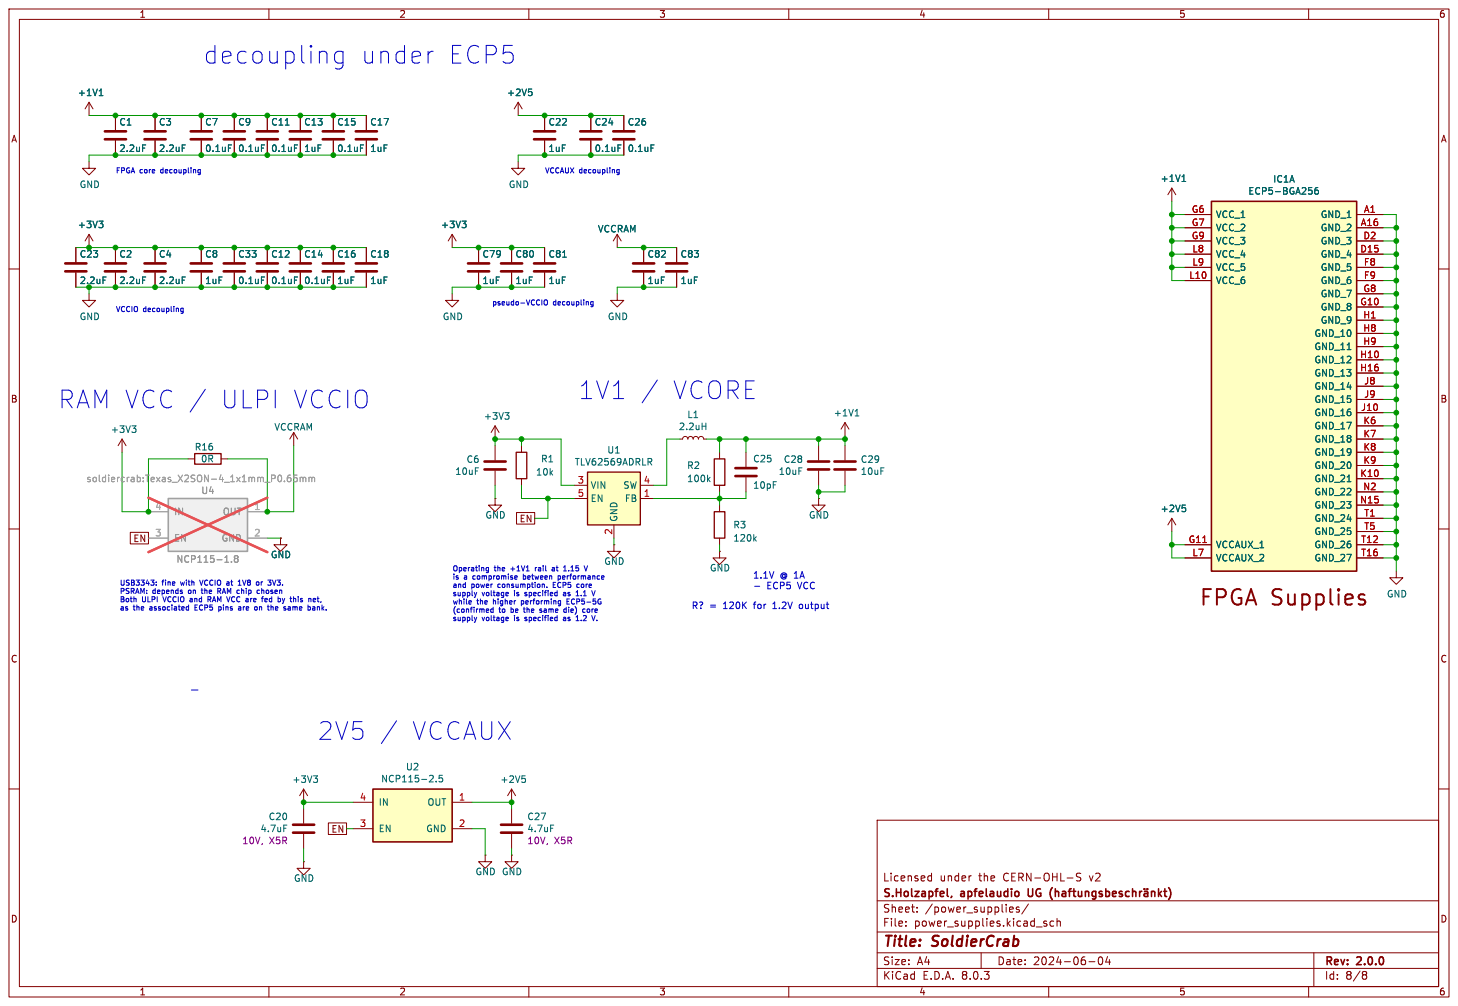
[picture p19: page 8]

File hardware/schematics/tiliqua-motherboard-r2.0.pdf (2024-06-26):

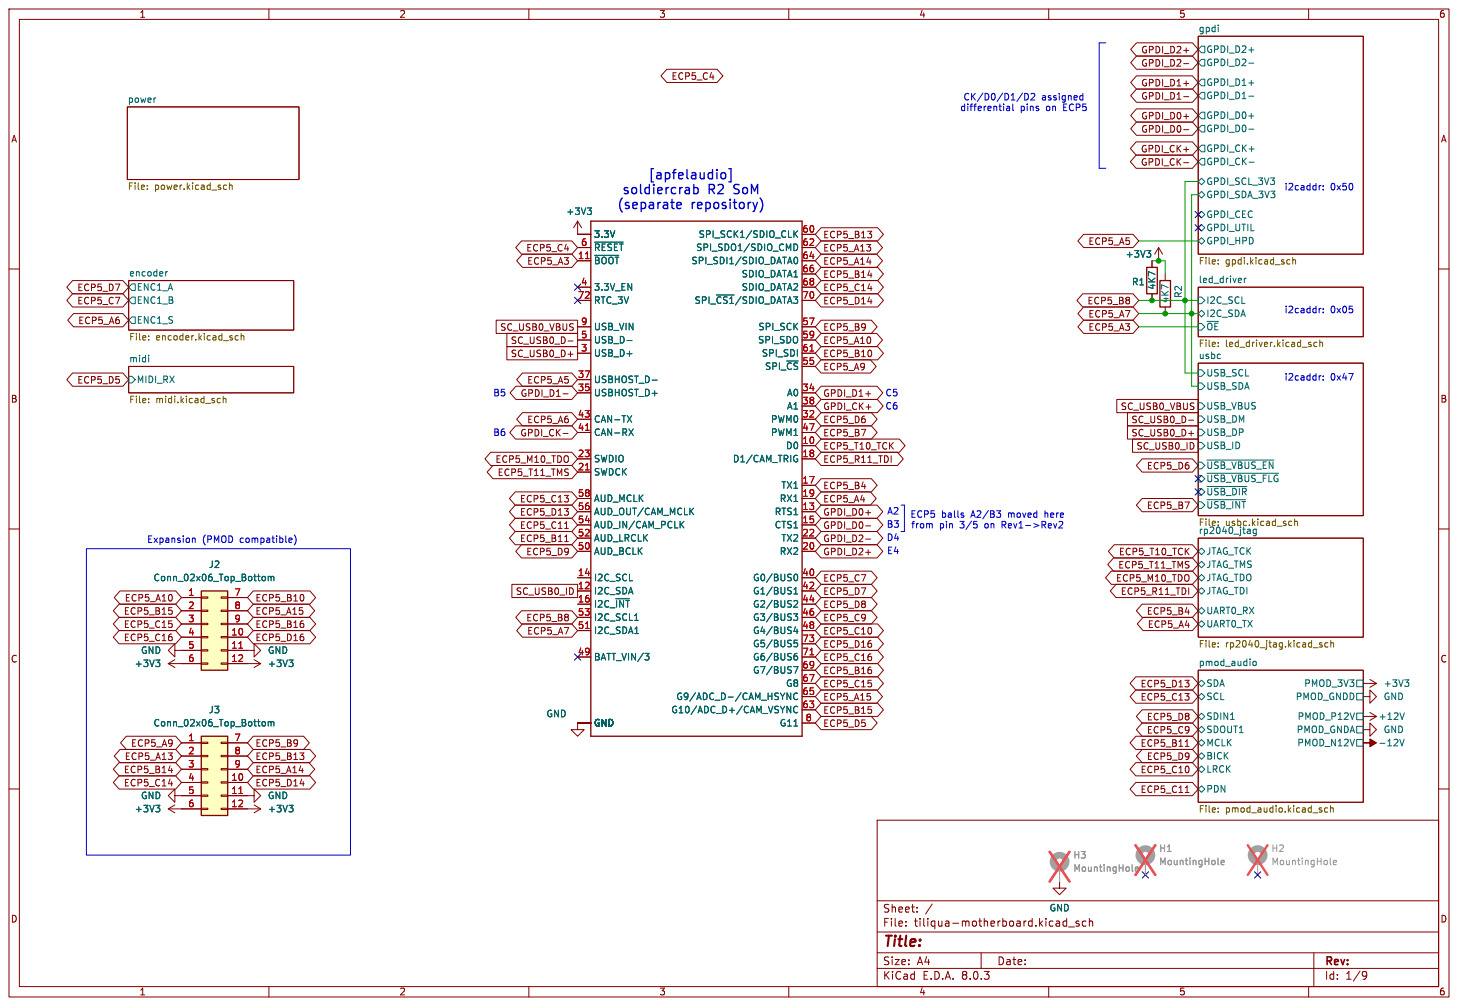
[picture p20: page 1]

Id: 1/9 Title: File: tiliqua-motherboard.kicad_sch Sheet: /

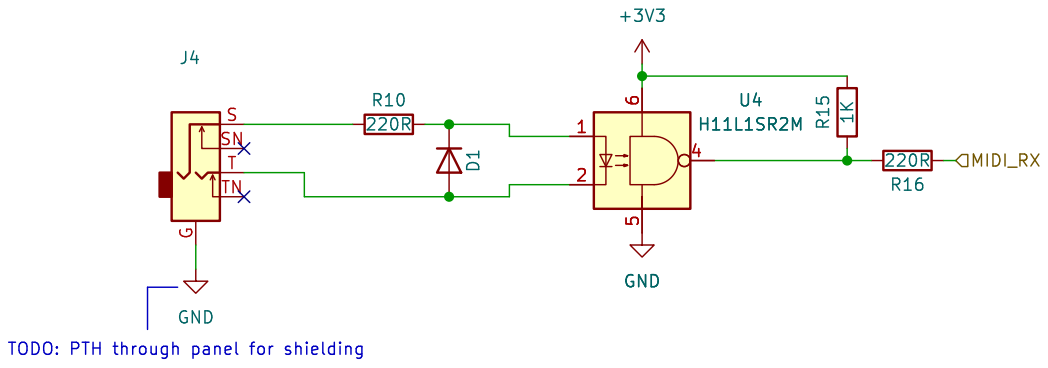
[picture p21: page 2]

Id: 3/9 Title: File: midi.kicad_sch Sheet: /midi/

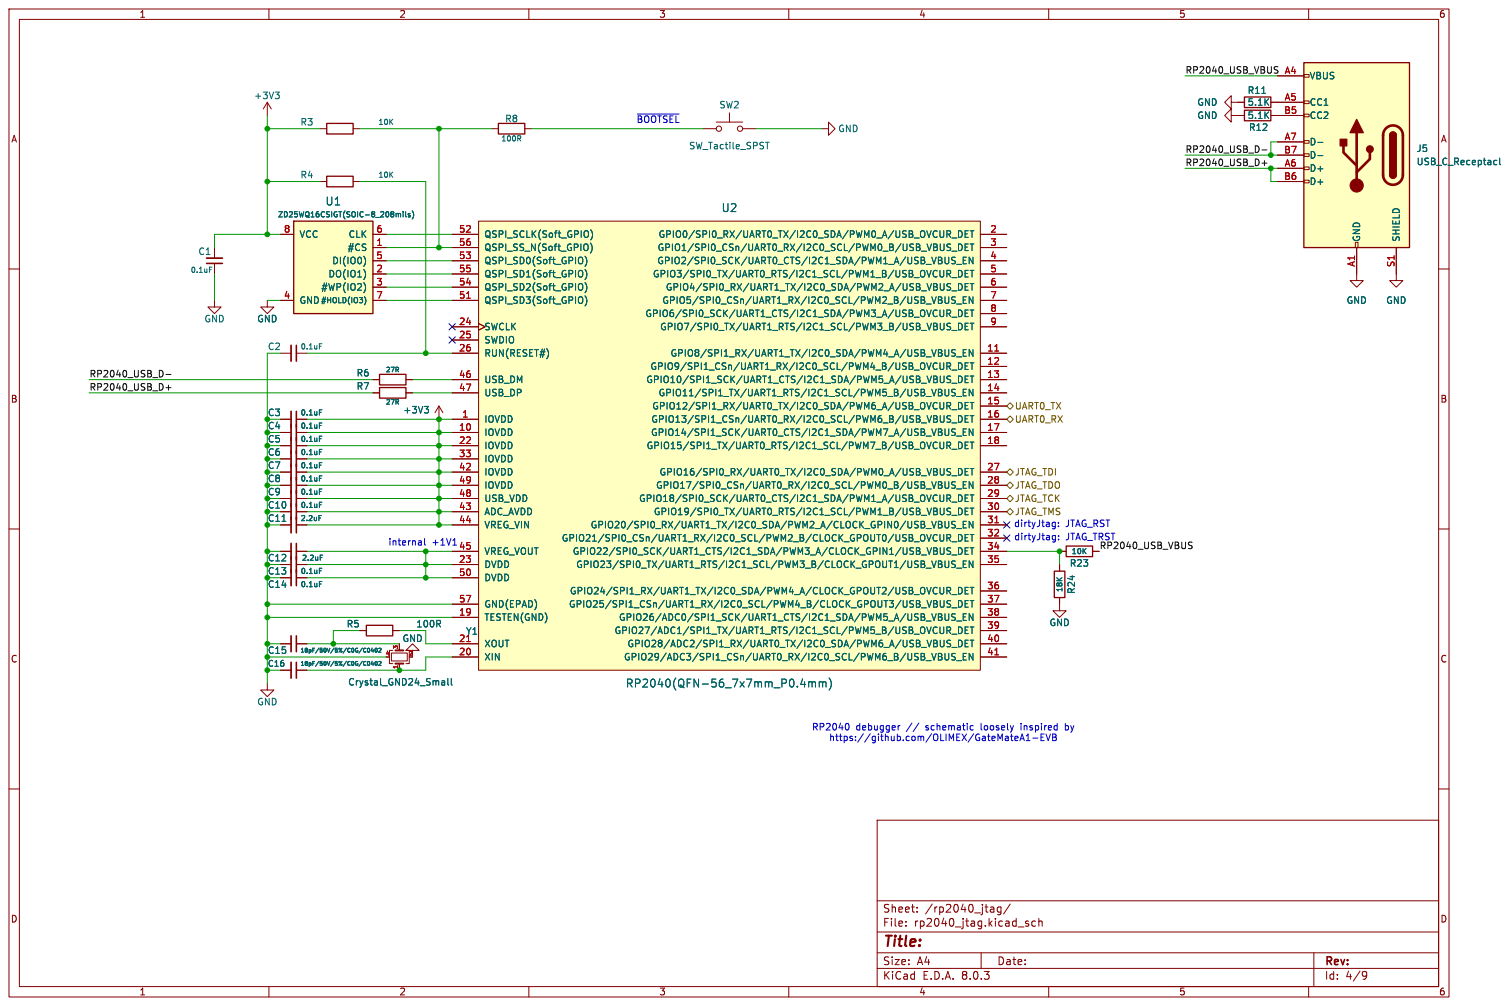
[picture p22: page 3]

Id: 4/9 Title: File: rp2040_jtag.kicad_sch Sheet: /rp2040_jtag/

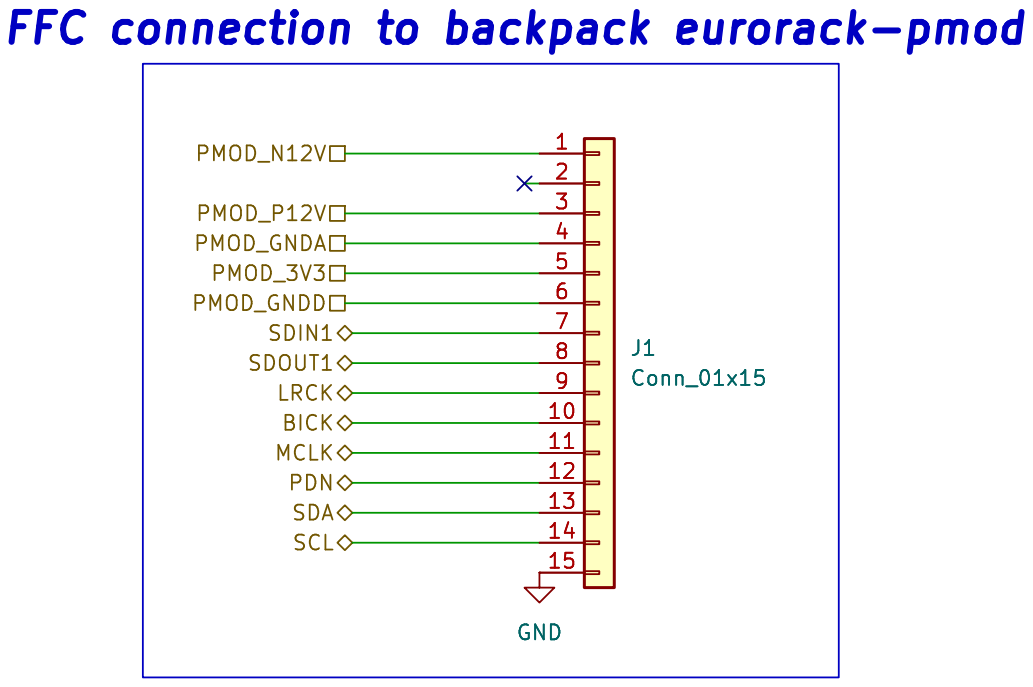
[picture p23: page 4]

SDIN1 SCL PMOD_N12V FFC connection to backpack eurorack-pmod

Id: 5/9 Title: File: pmod_audio.kicad_sch Sheet: /pmod_audio/


4 SW 5 BST 6 U5 AP63200WU GND GND GND

4 SW 5 BST 6 GND GND


CONN_CK+ CONN_D0- CONN_CK- CONN_D1- CONN_D2- CONN_D2+ CONN_D0+ CONN_D1+ DVI sink == +3V3 with 50ohm series pin_hi == 0mA

Id: 6/9 Title: File: gpdi.kicad_sch Sheet: /gpdi/



+3V3 GND GND GND GND

Id: 8/9 Title: File: led_driver.kicad_sch Sheet: /led_driver/


Id: 9/9 Title: File: usbc.kicad_sch Sheet: /usbc/

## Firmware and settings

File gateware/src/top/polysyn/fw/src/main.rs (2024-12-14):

#![no_std]
#![no_main]

use critical_section::Mutex;
use core::convert::TryInto;
use log::info;
use riscv_rt::entry;
use irq::handler;
use core::cell::RefCell;

use micromath::F32Ext;
use midi_types::*;
use midi_convert::render_slice::MidiRenderSlice;

use tiliqua_pac as pac;
use tiliqua_hal as hal;
use tiliqua_lib::*;
use tiliqua_lib::draw;
use tiliqua_lib::palette;
use tiliqua_lib::leds;
use tiliqua_lib::dsp::OnePoleSmoother;
use tiliqua_lib::midi::MidiTouchController;
use tiliqua_lib::generated_constants::*;
use tiliqua_fw::*;
use tiliqua_fw::opts::TouchControl;
use tiliqua_fw::opts::Screen;

use embedded_graphics::{
    pixelcolor::{Gray8, GrayColor},
    prelude::*,
};

use opts::Options;
use hal::pca9635::Pca9635Driver;

impl_ui!(UI,
         Options,
         Encoder0,
         Pca9635Driver<I2c0>,
         EurorackPmod0);

tiliqua_hal::impl_dma_display!(DMADisplay, H_ACTIVE, V_ACTIVE, VIDEO_ROTATE_90);

pub const TIMER0_ISR_PERIOD_MS: u32 = 5;

fn timer0_handler(app: &Mutex<RefCell<App>>) {

    critical_section::with(|cs| {

        let mut app = app.borrow_ref_mut(cs);

        //
        // Update UI and options
        //

        app.ui.update();

        if app.synth.midi_read() != 0 {
            app.ui.midi_activity()
        }

        //
        // Update synthesizer
        //

        let opts = app.ui.opts.clone();

        let drive_smooth = app.drive_smoother.proc_u16(opts.poly.drive.value);
        app.synth.set_drive(drive_smooth);

        let reso_smooth = app.reso_smoother.proc_u16(opts.poly.reso.value);
        app.synth.set_reso(reso_smooth);

        let diffuse_smooth = app.diffusion_smoother.proc_u16(opts.poly.diffuse.value);
        let coeff_dry: i32 = (32768 - diffuse_smooth) as i32;
        let coeff_wet: i32 = diffuse_smooth as i32;

        app.synth.set_matrix_coefficient(0, 0, coeff_dry);
        app.synth.set_matrix_coefficient(1, 1, coeff_dry);
        app.synth.set_matrix_coefficient(2, 2, coeff_dry);
        app.synth.set_matrix_coefficient(3, 3, coeff_dry);

        app.synth.set_matrix_coefficient(0, 4, coeff_wet);
        app.synth.set_matrix_coefficient(1, 5, coeff_wet);
        app.synth.set_matrix_coefficient(2, 6, coeff_wet);
        app.synth.set_matrix_coefficient(3, 7, coeff_wet);


        // Touch controller logic (sends MIDI to internal polysynth)
        if opts.poly.interface.value == TouchControl::On {
            app.ui.touch_led_mask(0b00111111);
            let touch = app.ui.pmod.touch();
            let jack = app.ui.pmod.jack();
            let msgs = app.touch_controller.update(&touch, jack);
            for msg in msgs {
                if msg != MidiMessage::Stop {
                    // TODO move MidiMessage rendering into HAL, perhaps
                    // even inside synth.midi_write.
                    let mut bytes = [0u8; 3];
                    msg.render_slice(&mut bytes);
                    let v: u32 = (bytes[2] as u32) << 16 |
                                 (bytes[1] as u32) << 8 |
                                 (bytes[0] as u32) << 0;
                    app.synth.midi_write(v);
                }
            }
        }

    });
}

pub fn write_palette(video: &mut Video0, p: palette::ColorPalette) {
    for i in 0..PX_INTENSITY_MAX {
        for h in 0..PX_HUE_MAX {
            let rgb = palette::compute_color(i, h, p);
            video.set_palette_rgb(i as u8, h as u8, rgb.r, rgb.g, rgb.b);
        }
    }
}

struct App {
    ui: UI,
    synth: Polysynth0,
    drive_smoother: OnePoleSmoother,
    reso_smoother: OnePoleSmoother,
    diffusion_smoother: OnePoleSmoother,
    touch_controller: MidiTouchController,
}

impl App {
    pub fn new(opts: Options) -> Self {
        let peripherals = unsafe { pac::Peripherals::steal() };
        let encoder = Encoder0::new(peripherals.ENCODER0);
        let pmod = EurorackPmod0::new(peripherals.PMOD0_PERIPH);
        let i2cdev = I2c0::new(peripherals.I2C0);
        let pca9635 = Pca9635Driver::new(i2cdev);
        let synth = Polysynth0::new(peripherals.SYNTH_PERIPH);
        let drive_smoother = OnePoleSmoother::new(0.05f32);
        let reso_smoother = OnePoleSmoother::new(0.05f32);
        let diffusion_smoother = OnePoleSmoother::new(0.05f32);
        let touch_controller = MidiTouchController::new();
        Self {
            ui: UI::new(opts, TIMER0_ISR_PERIOD_MS,
                        encoder, pca9635, pmod),
            synth,
            drive_smoother,
            reso_smoother,
            diffusion_smoother,
            touch_controller,
        }
    }
}

#[entry]
fn main() -> ! {
    let peripherals = pac::Peripherals::take().unwrap();
    let sysclk = pac::clock::sysclk();
    let serial = Serial0::new(peripherals.UART0);
    let mut timer = Timer0::new(peripherals.TIMER0, sysclk);
    let mut video = Video0::new(peripherals.VIDEO_PERIPH);
    let mut display = DMADisplay {
        framebuffer_base: PSRAM_FB_BASE as *mut u32,
    };
    crate::handlers::logger_init(serial);

    info!("Hello from Tiliqua POLYSYN!");

    let opts = opts::Options::new();
    let mut last_palette = opts.beam.palette.value.clone();
    let app = Mutex::new(RefCell::new(App::new(opts)));

    handler!(timer0 = || timer0_handler(&app));

    irq::scope(|s| {

        s.register(handlers::Interrupt::TIMER0, timer0);

        timer.enable_tick_isr(TIMER0_ISR_PERIOD_MS,
                              pac::Interrupt::TIMER0);

        let vscope  = peripherals.VECTOR_PERIPH;
        let mut first = true;

        loop {

            let (opts, notes, cutoffs) = critical_section::with(|cs| {
                let app = app.borrow_ref(cs);
                (app.ui.opts.clone(),
                 app.synth.voice_notes().clone(),
                 app.synth.voice_cutoffs().clone())
            });

            let help_screen: bool = opts.screen.value == Screen::Help;

            if opts.beam.palette.value != last_palette || first {
                write_palette(&mut video, opts.beam.palette.value);
                last_palette = opts.beam.palette.value;
            }

            if opts.draw || help_screen {
                draw::draw_options(&mut display, &opts, H_ACTIVE/2-30, 70,
                                   opts.beam.hue.value).ok();
                draw::draw_name(&mut display, H_ACTIVE/2, 30, opts.beam.hue.value, UI_NAME, UI_SHA).ok();
            }

            if help_screen {
                draw::draw_tiliqua(&mut display, H_ACTIVE/2-80, V_ACTIVE/2-200, opts.beam.hue.value,
                    [
                        "C2     phase",
                        "G2     -    ",
                        "C3     -    ",
                        "Eb3    -    ",
                        "G3     -    ",
                        "C4     -    ",
                        "-      out L",
                        "-      out R",
                    ],
                    [
                        "menu",
                        "-",
                        "video",
                        "-",
                        "-",
                        "midi notes (+mod, +pitch)",
                    ],
                    "[8-voice polyphonic synthesizer]",
                    "The synthesizer can be controlled by touching\n\
                    jacks 0-5 or using a MIDI keyboard through TRS\n\
                    midi. Control source is selected in the menu.\n\
                    \n\
                    In touch mode, the touch magnitude controls the\n\
                    filter envelopes of each voice. In MIDI mode\n\
                    the velocity of each note as well as the value\n\
                    of the modulation wheel affects the filter\n\
                    envelopes.\n\
                    \n\
                    Output audio is sent to output channels 2 and\n\
                    3 (last 2 jacks). Input jack 0 also controls\n\
                    phase modulation of all oscillators, so you\n\
                    can patch input jack 0 to an LFO for retro-sounding\n\
                    slow vibrato, or to an oscillator for some wierd\n\
                    FM effects.\n\
                    \n\
                    * Use encoder and encoder button to navigate menu.\n\
                    * Switch away from the HELP screen to start visuals.\n\
                    * Hold encoder for 3sec to enter bootloader.\n\
                    ",
                    ).ok();
                // Enough persistance to reduce flicker on loads of text.
                video.set_persist(2048);
                video.set_decay(1);
                vscope.en().write(|w| w.enable().bit(false) );
            } else {
                video.set_persist(opts.beam.persist.value);
                video.set_decay(opts.beam.decay.value);
                vscope.en().write(|w| w.enable().bit(true) );
            }

            vscope.hue().write(|w| unsafe { w.hue().bits(opts.beam.hue.value) } );
            vscope.intensity().write(|w| unsafe { w.intensity().bits(opts.beam.intensity.value) } );
            vscope.xscale().write(|w| unsafe { w.xscale().bits(opts.vector.xscale.value) } );
            vscope.yscale().write(|w| unsafe { w.yscale().bits(opts.vector.yscale.value) } );

            if !help_screen {
                for ix in 0usize..N_VOICES {
                    let j = (N_VOICES-1)-ix;
                    draw::draw_voice(&mut display,
                                     ((H_ACTIVE as f32)/2.0f32 + 330.0f32*f32::cos(2.3f32 + 2.0f32 * j as f32 / (N_VOICES as f32))) as i32,
                                     ((V_ACTIVE as f32)/2.0f32 + 330.0f32*f32::sin(2.3f32 + 2.0f32 * j as f32 / (N_VOICES as f32))) as u32 - 15,
                                     notes[ix], cutoffs[ix], opts.beam.hue.value).ok();
                }
            }

            first = false;
        }
    })
}

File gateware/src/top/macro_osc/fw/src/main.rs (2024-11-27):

// See top-level comment in 'top.py' for usage information.

#![no_std]
#![no_main]

use log::info;
use riscv_rt::entry;
use core::cell::RefCell;
use critical_section::Mutex;
use core::convert::TryInto;
use irq::handler;
use embedded_alloc::LlffHeap as Heap;
use mi_plaits_dsp::dsp::voice::{Modulations, Patch, Voice};
use embedded_graphics::{
    pixelcolor::{Gray8, GrayColor},
    prelude::*,
};

use tiliqua_pac as pac;
use tiliqua_hal as hal;
use tiliqua_fw::*;
use tiliqua_lib::*;
use tiliqua_lib::generated_constants::*;
use opts::Options;
use hal::pca9635::*;


tiliqua_hal::impl_dma_display!(DMADisplay, H_ACTIVE, V_ACTIVE, VIDEO_ROTATE_90);

impl_ui!(UI,
         Options,
         Encoder0,
         Pca9635Driver<I2c0>,
         EurorackPmod0);

pub const TIMER0_ISR_PERIOD_MS: u32 = 5;
const BLOCK_SIZE: usize = 64;
// PSRAM heap for big audio buffers.
const HEAP_START: usize = PSRAM_BASE + (PSRAM_SZ_BYTES / 2);
const HEAP_SIZE: usize = 128*1024;

static HEAP: Heap = Heap::empty();

struct App<'a> {
    voice: Voice<'a>,
    patch: Patch,
    modulations: Modulations,
    ui: UI,
}

impl<'a> App<'a> {
    pub fn new(opts: Options) -> Self {
        let mut voice = Voice::new(&HEAP, BLOCK_SIZE);
        let mut patch = Patch::default();

        patch.engine = 0;
        patch.harmonics = 0.5;
        patch.timbre = 0.5;
        patch.morph = 0.5;
        patch.timbre_modulation_amount = 0.5;
        patch.morph_modulation_amount  = 0.5;
        voice.init();

        let peripherals = unsafe { pac::Peripherals::steal() };
        let encoder = Encoder0::new(peripherals.ENCODER0);
        let i2cdev = I2c0::new(peripherals.I2C0);
        let pca9635 = Pca9635Driver::new(i2cdev);
        let pmod = EurorackPmod0::new(peripherals.PMOD0_PERIPH);

        Self {
            voice,
            patch,
            modulations: Modulations::default(),
            ui: UI::new(opts, TIMER0_ISR_PERIOD_MS, encoder,
                        pca9635, pmod),
        }
    }
}

// TODO: move this to hardware as it is quite expensive.
#[inline(always)]
pub fn f32_to_i32(f: u32) -> i32 {
    let a = f & !0 >> 1; // Remove sign bit.
    if a < 127 << 23 { // >= 0, < 1
        0
    } else if a < 158 << 23 { // >= 1, < max
        let m = 1 << 31 | a << 8; // Mantissa and the implicit 1-bit.
        let s = 158 - (a >> 23); // Shift based on the exponent and bias.
        let u = (m >> s) as i32; // Unsigned result.
        if (f as i32) < 0 { -u } else { u }
    } else  { // >= max (incl. inf)
        if (f as i32) < 0 { i32::MIN } else { i32::MAX }
    }
}

fn timer0_handler(app: &Mutex<RefCell<App>>) {

    let peripherals = unsafe { pac::Peripherals::steal() };
    let audio_fifo = peripherals.AUDIO_FIFO;
    let pmod = peripherals.PMOD0_PERIPH;

    critical_section::with(|cs| {

        let mut app = app.borrow_ref_mut(cs);

        //
        // Update UI and options
        //

        app.ui.update();

        //
        // Patch settings from UI
        //

        let opts = app.ui.opts.clone();
        let mut patch = app.patch.clone();

        patch.engine    = opts.osc.engine.value as usize;
        patch.note      = opts.osc.note.value as f32;
        patch.harmonics = (opts.osc.harmonics.value as f32) / 256.0f32;
        patch.timbre    = (opts.osc.timbre.value as f32) / 256.0f32;
        patch.morph     = (opts.osc.morph.value as f32) / 256.0f32;

        //
        // Modulation sources from jacks
        //

        let mut modulations = app.modulations.clone();
        let jack = pmod.jack().read().bits();

        let note_patched = (jack & 0x1) != 0;
        modulations.trigger_patched   = (jack & 0x2) != 0;
        modulations.timbre_patched    = (jack & 0x4) != 0;
        modulations.morph_patched     = (jack & 0x8) != 0;

        if note_patched {
            // 1V/oct
            let v_oct = ((pmod.sample_i0().read().bits() as i16) as f32) / 4096.0f32;
            modulations.note = v_oct * 12.0f32;
        }

        modulations.trigger = ((pmod.sample_i1().read().bits() as i16) as f32) / 16384.0f32;
        modulations.timbre = ((pmod.sample_i2().read().bits() as i16) as f32) / 16384.0f32;
        modulations.morph = ((pmod.sample_i3().read().bits() as i16) as f32) / 16384.0f32;

        //
        // Render audio
        //

        let mut out = [0.0f32; BLOCK_SIZE];
        let mut aux = [0.0f32; BLOCK_SIZE];

        let mut n_attempts = 0;
        while (audio_fifo.fifo_len().read().bits() as usize) < AUDIO_FIFO_ELASTIC_SZ - BLOCK_SIZE {
            n_attempts += 1;
            if n_attempts > 10 {
                // TODO set underrun flag
                break
            }
            app.voice
               .render(&patch, &modulations, &mut out, &mut aux);
            for i in 0..BLOCK_SIZE {
                unsafe {
                    let fifo_base = AUDIO_FIFO_MEM_BASE as *mut u32;
                    *fifo_base = f32_to_i32((out[i]*16000.0f32).to_bits()) as u32;
                    *fifo_base.add(1) = f32_to_i32((aux[i]*16000.0f32).to_bits()) as u32;
                }
            }
        }

    });
}

pub fn write_palette(video: &mut Video0, p: palette::ColorPalette) {
    for i in 0..PX_INTENSITY_MAX {
        for h in 0..PX_HUE_MAX {
            let rgb = palette::compute_color(i, h, p);
            video.set_palette_rgb(i as u8, h as u8, rgb.r, rgb.g, rgb.b);
        }
    }
}
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

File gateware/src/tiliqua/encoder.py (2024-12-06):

# Logic for dealing with rotary encoders.
#
# Copyright (c) 2024 S. Holzapfel <me@sebholzapfel.com>
#
# SPDX-License-Identifier: BSD-3-Clause

from amaranth                    import *
from amaranth.lib                import wiring, data
from amaranth.lib.wiring         import Component, In, Out, flipped, connect
from amaranth.lib.cdc            import FFSynchronizer
from amaranth_soc                import csr

class IQDecode(wiring.Component):

    iq: In(unsigned(2))
    step: Out(unsigned(1))
    direction: Out(unsigned(1))

    def __init__(self):
        super().__init__()
        self.iq_history = Array(Signal(2) for _ in range(2))

    def elaborate(self, _platform):
        m = Module()
        iq_sync = Signal(unsigned(2))
        m.submodules += FFSynchronizer(self.iq, iq_sync, reset=0)
        m.d.sync += self.iq_history[1].eq(self.iq_history[0]),
        m.d.sync += self.iq_history[0].eq(iq_sync),
        m.d.comb += self.step.eq(Cat(self.iq_history).xor()),
        m.d.comb += self.direction.eq(Cat(self.iq_history[1][0],
                                          self.iq_history[0][1]).xor()),
        return m

class PinSignature(wiring.Signature):
    def __init__(self):
        super().__init__({
            "i":  In(unsigned(1)),
            "q":  In(unsigned(1)),
            "s":  In(unsigned(1)),
        })

class Provider(Component):
    def __init__(self):
        super().__init__({
            "pins": In(PinSignature())
        })

    def elaborate(self, platform):
        m = Module()
        enc = platform.request("encoder")
        m.d.comb += [
            self.pins.i.eq(enc.i.i),
            self.pins.q.eq(enc.q.i),
            self.pins.s.eq(enc.s.i),
        ]
        return m

class Peripheral(wiring.Component):

    class StepReg(csr.Register, access="r"):
        step: csr.Field(csr.action.R, signed(8))

    class ButtonReg(csr.Register, access="r"):
        button: csr.Field(csr.action.R, unsigned(1))

    def __init__(self, **kwargs):
        self.iq_decode = IQDecode()

        regs = csr.Builder(addr_width=5, data_width=8)

        self._step = regs.add("step", self.StepReg())
        self._button = regs.add("button", self.ButtonReg())

        self._bridge = csr.Bridge(regs.as_memory_map())

        super().__init__({
            "bus": In(csr.Signature(addr_width=regs.addr_width, data_width=regs.data_width)),
            "pins": Out(PinSignature()),
        })
        self.bus.memory_map = self._bridge.bus.memory_map

    def elaborate(self, platform):
        m = Module()
        m.submodules.bridge = self._bridge
        m.submodules.iq_decode = self.iq_decode

        connect(m, flipped(self.bus), self._bridge.bus)

        read_occurred = Signal()
        d_steps = Signal(signed(8))

        m.d.comb += self.iq_decode.iq.eq(Cat(self.pins.i, self.pins.q))
        m.d.comb += self._step.f.step.r_data.eq(d_steps)

        button_sync = Signal()
        m.submodules += FFSynchronizer(self.pins.s, button_sync, reset=0)
        m.d.comb += self._button.f.button.r_data.eq(button_sync)

        with m.If(self._step.f.step.r_stb):
            m.d.sync += read_occurred.eq(1)

        with m.If(self.iq_decode.step):
            with m.If(self.iq_decode.direction):
                m.d.sync += d_steps.eq(d_steps + 1)
            with m.Else():
                m.d.sync += d_steps.eq(d_steps - 1)
        with m.Else():
            with m.If(read_occurred):
                m.d.sync += read_occurred.eq(0)
                m.d.sync += d_steps.eq(0)

        return m

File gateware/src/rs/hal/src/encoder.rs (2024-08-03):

#[macro_export]
macro_rules! impl_encoder {
    ($(
        $ENCODERX:ident: $PACENCODERX:ty,
    )+) => {
        $(
            #[derive(Debug)]
            pub struct $ENCODERX {
                registers: $PACENCODERX,

                rot: i16,
                lrot: i16,
                lbtn: bool,

                pending_ticks: i8,
                pending_release: bool,
                pending_press:   bool,
            }

            impl $ENCODERX {
                pub fn new(registers: $PACENCODERX) -> Self {
                    let btn = registers.button().read().bits() != 0;
                    Self { registers,
                           rot: 0,
                           lrot: 0,
                           lbtn: btn,
                           pending_ticks: 0,
                           pending_release: false,
                           pending_press: false
                    }
                }

                /// Check for pending ticks and clear them.
                pub fn poke_ticks(&mut self) -> i8 {
                    let ticks = self.pending_ticks;
                    self.pending_ticks = 0;
                    ticks
                }

                /// Check for pending clicks and erase it.
                pub fn poke_btn(&mut self) -> bool {
                    let btn = self.pending_press && self.pending_release;
                    if btn {
                        self.pending_press = false;
                        self.pending_release = false;
                    }
                    btn
                }

                pub fn update(&mut self) {

                    self.rot += (self.registers.step().read().bits() as i8) as i16;
                    let btn = self.registers.button().read().bits() != 0;
                    let mut delta_ticks = self.rot - self.lrot;

                    // This logic is dumb. Move it into RTL.

                    while delta_ticks > 1 {
                        self.pending_ticks += 1;
                        delta_ticks -= 2;
                    }

                    while delta_ticks < -1 {
                        self.pending_ticks -= 1;
                        delta_ticks += 2;
                    }

                    // button just released
                    if self.lbtn != btn {
                        if btn {
                            self.pending_press = true;
                        } else {
                            self.pending_release = true;
                        }
                    }

                    self.lrot = self.rot - delta_ticks;
                    self.lbtn = btn;
                }
            }

            impl From<$PACENCODERX> for $ENCODERX {
                fn from(registers: $PACENCODERX) -> $ENCODERX {
                    $ENCODERX::new(registers)
                }
            }
        )+
    }
}

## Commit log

2024-03-30 some rearranging
    [backpack.kicad_pcb]
2024-03-30 start power
    [backpack.kicad_pcb, backpack.kicad_sch, power.kicad_sch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]
2024-03-31 start on regs
    [power.kicad_sch]
2024-03-31 parts and capture done sans most needing future pinswaps
    [backpack.kicad_pcb, backpack.kicad_sch, power.kicad_sch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]
2024-03-31 aux vin over usb
    [backpack.kicad_sch, power.kicad_sch]
2024-04-01 connections + placement done
    [backpack.kicad_pcb, backpack.kicad_sch, power.kicad_sch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]
2024-04-01 place 2 leds, route 2nd button to both FPGA and RP2040
    [backpack.kicad_pcb, backpack.kicad_sch, rp2040_jtag.kicad_sch]
2024-04-02 fix footprint errors and pin assignments on ffc
    [backpack.kicad_pcb, backpack.kicad_sch, midi.kicad_sch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]
2024-04-02 fix pmod spacing
    [backpack.kicad_pcb]
2024-04-03 routing done
    [backpack.kicad_pcb]
2024-04-03 clean up some routing
    [backpack.kicad_pcb]
2024-04-04 add some silk designators
    [backpack.kicad_pcb]
2024-04-04 tiliqua, m.2 footprint move/fix, lcsc# for m.2
    [backpack.kicad_pcb, backpack.kicad_sch]
2024-04-04 some final cross-checks
    [backpack.kicad_pcb]
2024-04-04 commit before bomfix
    [backpack_bom_jlc.csv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]
2024-04-04 updates before fab 04-04-24
    [backpack.csv, backpack.kicad_pcb, backpack.kicad_sch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]
2024-04-04 fix mask expansion on j8 - not submitted yet!
    [backpack.kicad_pcb]
2024-04-07 panel proto1
    [eurorack-pmod-panel.kicad_pcb, eurorack-pmod-panel.kicad_sch]
2024-04-07 fab panel proto1
    [eurorack-pmod-panel.kicad_pcb]
2024-04-30 fab panel proto2
    [eurorack-pmod-panel.kicad_pcb]
2024-04-30 Add LICENSE, update README, rename all paths
    [backpack_bom_jlc.csv, midi.kicad_sch, pmod_audio.kicad_sch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]
2024-05-01 switch example gateware to run with 'pdm install' + 'pdm run build_tiliqu'
2024-05-05 switch to wiring.connect with resetless hack?
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2024-05-05 try internal wiring in AudioStream - verilog looks like connections don't happen?
2024-05-05 Revert "try internal wiring in AudioStream - verilog looks like connections don't happen?"
    This reverts commit eb6e107fcbc3f98641982b3db8ca396e271bf7aa.
    [eurorack_pmod.py]
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2024-05-06 fixed-point VCA passthrough works
    [eurorack_pmod.py]
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2024-05-09 gateware/dsp: fix PitchShift delayline addressing
    [dsp.py]
2024-05-10 gateware/dsp: fix MatrixMix negative coefficients, improve delay matrix
    [dsp.py]
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2024-05-28 dsp/resample/fir: import fixes from hardware testing
    [dsp.py]
2024-05-31 dsp/resample: fix bug in downsampling logic
    [dsp.py]
2024-06-01 resample nco doesn't work on hardware
    [dsp.py]
2024-06-01 works in sim, matrix mix broke it?
    [sim.py]
2024-06-15 gateware: add compressed ila, update luna/usb dependencies (#10)
    * Switch to latest eurorack-pmod libraries with some timing fixes (s/clk_fs/fs_strobe)
    * Rebase Iso work on top of latest LUNA (has some bugfixes)
    * Vendor in the ILA from LUNA, modify it such that we only store waveform changes (basic RLE-like compression). This is important for being able to see audio signals at a 60Mhz system clock.
    * Update the USB audio example to import some changes from upstream work
    * Add optional ILA build to USB audio example (I used it to debug sample rate feedback).
    [eurorack_pmod.py]
2024-06-17 gateware/dsp: fix matrix coeff update bug, reduce svf multiplier usage 3 -> 1
    [dsp.py]
2024-06-19 example_soc: add psram support, memtest OK (#14)
    * example_soc: psram+memtest (errors across boundaries)
    * vendor/psram: vendor in and fix clock gating on recovery (fixes memtest)
    * example_soc/fw: add default trap handlers
    [main.rs, psram_peripheral.py, tiliqua_platform.py]
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2024-06-22 gateware/i2c: implement i2c peripheral, integrate in `example_soc` (#15)
    Tiliqua R2 has a few I2C peripherals, so we need an I2C core that can be driven by the SoC. This one is largely based on the `transaction()` semantics from rust `embedded-hal` v1.0.0 - the exact sema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
2024-06-26 example_soc/hal: vendor & bump embedded-hal to 1.0.0, add i2c hal implementation (#16)
    * vendor in the useful parts of lunasoc-hal and upgrade traits to embedded-hal 1.0.0
    * add i2c implementation compatible with embedded-hal 1.0.0
2024-06-26 hardware/r2: squash in all changes for tiliqua R2 (#17)
    * squash in all changes for Tiliqua R2
    * add schematics for all components of Tiliqua R2
    * update README and add lightbox photos
    [encoder.kicad_sch, gpdi.kicad_sch, led_driver.kicad_sch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]
2024-06-26 gateware/r2: encoder peripheral, cleanup platform definitions (#18)
    * update all platform definitions for r2
    * add gateware for rotary encoder
    * fix bad arguments for dsp examples
    [encoder.py, main.rs, tiliqua_platform.py]
2024-07-06 gateware/video: fix clock domain crossing before DVI PHY (#22)
    * 1280x720p60 mode at 50p on 60Mhz PLL tested on Dell + HGB + Projector
    * 800x600p60 mode on 40MHz PLL (default) tested on the same 3 displays.
    * hsync/vsync cut registers should be in dvi domain
2024-07-10 gateware/example_soc: cleanup, add framebuffer (#23)
    * add simple embedded-graphics target to example_soc, draw some things
    * move generic video logic into dedicated library
2024-07-13 Port menu system, cleanup SoC structure, various bug fixes (#24)
    * Port over encoder-driven menu system from my polyvec project
    * Move more drivers and common logic into library directory `rs`
    * Move rasterization logic into separate library
    * Rename example_soc to `selftest`
    * Add a new project `xbeam`, which is an improved vectorscope with SoC + menu system
    [encoder.rs, eurorack_pmod.py, i2c.rs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]
2024-07-17 gateware/xbeam: route SoC menu system to all LEDs (#25)
    * for non-video cores, this will enable using the UI without a display.
    * need to figure out how to make this generic across all cores.
2024-07-26 Improve video timings, set default to 1280x720p60 (#26)
    * Rewrite timing generator to get closer to DVI spec
    * Set default resolution to 1280x720p60
    * Increase drive and slew, 8mA is still <10mA (spec) but we don't want the ECP5 to get too hot.
    * Extra registers in TMDS serializer to improve timing
    [main.rs, raster.py, tiliqua_platform.py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]
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2024-08-03 gateware: add multiboot support (#28)
    * add `boot` bitstream project, which allows you to select which bitstream to reconfigure to using a menu system shown on the LEDs (no screen) or on an attached display (with screen). No PC or USB co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
    *the `boot` bitstream communicates with the RP2040 over UART to ask for reconfiguration to an arbitrary bitstream, crucially WITHOUT requiring writes to the FPGA's SPI flash (as they are finite). Doc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
2024-08-04 gateware: video switching, generate more SoC constants (#29)
    * Allow specifying video resolution and PLL settings using single `TILIQUA_RESOLUTION` environment variable.
    * Collapse all SoC examples such that they share a core implementation
    * Generate some Rust constants during SoC elaboration to remove duplication
2024-08-11 gateware/poly: split out & rewrite midi/touch polysynth (#30)
    * split out midi/touch polysynth into self-contained bitstream with menu system
    * add DSP stream shorthand for setting VALID/READY bits, and field remapping
    * add coefficient update support to Matrix mixer, used by the SoC to control diffusion dry/wet
    * add a visualization of voice LPF states
    * add an environment variable TILIQUA_VIDEO_ROTATE=1 for 90 degree rotation (required for circle screen)
    [dsp.py, lib.rs, main.rs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]
2024-08-25 poly/xbeam: add color palette selection (#32)
    * expose palette memory that decodes pixels from RAM into screen colors
    * allow the palette memory to be tweaked by the SoC
    * add a menu option to change the palette to xbeam and poly
    * start with linear, exponential, grayscale and inverted palettes
    [lib.rs, main.rs, tiliqua_soc.py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]
2024-08-25 gateware: clean up some firmware duplication (#33)
    * factor out bargraph LED logic and encoder tick consumption
    * remove duplication of `handlers.rs`
    * center boot screen
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2024-09-07 still works on reverting bootrom backport
    [tiliqua_soc.py]
2024-09-07 modify soc timer, so we can oneshot in a similar way to previously
2024-09-07 tiliqua/i2c: reset error flag on transaction start
    [i2c.py, i2c.rs]
2024-09-08 gateware: group SoC registers using subfields (#35) * group SoC registers using subfields, where it is cleaner * add explicit register offsets for cases where `w_stb` collides between sub-fields (not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
    [i2c.py, i2c.rs, main.rs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]
2024-09-08 gateware/soc: modify vexriscv configuration, reduce firmware bloat (#36) * fix vexriscv sbt build scripts so its easier to modify in-place * modify vexriscv configuration to remove icache, not necess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
    [main.rs, tiliqua_soc.py, video.py]
2024-09-10 support simulating entire `selftest` SoC, including firmware (#37)
    * add support for simulating entire `selftest` SoC with firmware, using `pdm sim_selftest`.
    * implement simulation harness for SoCs, which includes DVI out to bitmaps on host and UART prints to stdio on host
    * clean up existing simulation infrastructure, use dedicated FakePSRAMSimulationInterface for bubbling up internal state to the external simulation harness.
2024-09-21 tiliqua_platform: replace audio PLL with 12.5MHz / 50.0MHz from first PLL
    [tiliqua_platform.py]
2024-09-21 video/raster: fix wishbone DMA logic errors from oSPI testing
    [raster.py, video.py]
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2024-09-21 vendor/psram: sim runs against actual psram controller, fix register writes
    [psram_peripheral.py]
2024-09-21 tiliqua_platform: rework to support both SC2 + SC3
    [tiliqua_platform.py, tiliqua_soc.py]
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2024-09-21 bootstub: fix, better CLI for amaranth overrides
    [tiliqua_soc.py]
2024-09-21 example_vectorscop/usb_audio: fix synthesis with --ila
    [tiliqua_soc.py]
2024-09-21 example_dsp: fix build/sim with top_level_cli
    [cli.py, sim.py]
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2024-09-22 cli: fix --flash action
    [cli.py]
2024-09-22 polysyn/xbeam: fix build + sim
    [sim.py, tiliqua_soc.py]
2024-09-23 fixed: squash warnings, s/sas_value/raw
    [dsp.py, raster.py, scope.py]
2024-09-23 fixed: squash more warnings, implement __eq__, from_bits
    [eurorack_pmod.py]
2024-09-24 vendor/i2c: switch from luna to glasgow i2c impl to squash Record warnings
2024-09-25 cli: add --noflatten option, workaround for yosys/issues/4349 * name all submodules in TiliquaSoc * remove hdl.mem usage in vectorscope_no_soc
    [cli.py, dsp.py, tiliqua_soc.py]
2024-09-26 cache: fix RAM inference
    [cache.py]
2024-10-02 Add support for PSRAM-backed delay lines and audio effects (#48)
    * Rewrite `DelayLine` implementation so it can be PSRAM- or SRAM- backed.
    * Add a bunch of examples of using this (ping-pong delay, diffuser etc) both in PSRAM and SRAM case.
    At the moment the wishbone L2 cache is not sufficient for us to get maximum memory bandwidth performance (no real burst accesses), however adding burst support to WishboneL2Cache I'll keep as a follo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
2024-10-09 cache/delay_line: improvements for psram-backed pitch shifting (#54)
    A bunch of improvements to `DelayLine` & `Cache` to facilitate psram-backed pitch shifting:
    - `cache`: reduce memory access port shape to 32-bit always (fix RAM inference)
    - `cache`: add switch to select LUTRAM or dual-port RAM as backing store
    - `delayline`: fix logic where zero delay is requested
    - `test_delayln`: parameterize test cases and add more coverage
    - `top/dsp`: modify `pitch` example to be PSRAM-backed with much longer grain size
    [cache.py, delay_line.py]
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2024-10-12 pll: add hi-res audio PLLs for LFE5U-45/SC2 platform, update PIDs (#57)
    - Re-add hi-res audio PLLs (12.288MHz) on -45k ECP5 platform (default platform)
    - Keep using approximate audio PLLs (12.5 MHz) on -25k ECP5 platform (`--sc3` flag)
    - Switch USB VID/PID to match https://pid.codes/1209/AA62/
    Longer term solution that should work on both platforms: https://github.com/apfelaudio/tiliqua/issues/55
    [tiliqua_platform.py, tiliqua_pll.py]
2024-10-12 tiliqua_platform: add RebootProvider and use it where needed
    [tiliqua_platform.py, tiliqua_soc.py]
2024-10-13 dsp: implement polyphase resampler (#60)
    - Add optimization to `FIR` implementation so you can use the 'stride' argument to avoid performing MACs or needing tap storage for samples that are expected to always be zero.
    - Update `Resample` to use this field, meaning it is now a polyphase resampler.
    - Add some test cases comparing `Resample` and `FIR` outputs to `scipy.signal` outputs.
    - TODO: `n_up` (numerators) must currently be a power of 2, however it should not be so hard to remove this restriction (useful for some common audio ratios e.g 44100 / 48000).
    [dsp.py]
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2024-10-30 midi/voicetracker: rewrite and document * Pitch bend support (needs 2 multipliers) * More sensible voice culling (no longer round-robin) * Integrate frequency conversion table * Add test coverage
    [midi.py]
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2024-11-05 usb/host: add basic USB MIDI host implementation and demo (#65)
    * Extremely bare-bones USB host logic intended for using Tiliqua as a USB MIDI host, initially as a MIDI/CV converter.
    * Built by wiring together a lot of existing LUNA components out-of-tree and adding some things (SOF/token generation, host reset and setup phase logic).
    * Intended solely for hardware validation at the moment, still requires extensive testing across different MIDI devices as well as automatically reading the descriptors to select the correct interface.
    * Some unrelated improvements:
    * Fix ILA timestamping
    * Move MidiCV logic to common `midi.py` library and remove deprecated Amaranth constructs.
    [midi.py, usb_host.py]
2024-11-06 polysyn: fix MIDI byte order
    [main.rs]
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2024-11-11 tiliqua_soc: move firmware images to SPI flash, fix timer interrupts (#68)
    * Fix timer interrupts and introduce in `xbeam`, `polysyn`, `bootloader` with `irq` / `scoped_irq` crates.
    * Factor out LED/encoder UI / options modification into shared UI macro
    * Also, improve this so selected page is displayed on the LEDs in green.
    * This means it's possible to navigate the whole menu system without a screen.
    * Move most firmware images into SPI flash (only bootloader firmware remains in BRAM)
    * Add support for this in simulation so SoC simulation still works regardless of whether the firmware is in BRAM or spiflash.
    * Switch from `riscv32imac` to `riscv32im` CPU/toolchain as it seems f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
    [cli.py, lib.rs, main.rs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]
2024-11-12 top/macro_osc: add SoC variant with FPU, add 'macro oscillator' example bitstream (#69)
    * Add SoC variant that implements `rv32imafc` extensions (with FPU and compressed instructions).
    * As a demo of this new variant, add a `macro_osc` top-level bitstream that does some expensive DSP in a softcore using the FPU and streams it glitch-free to the audio outputs.
    ---
    'Macro-Oscillator' runs a downsampled version of the DSP code from a
    famous Eurorack module (credits below), on a softcore, to demonstrate the
    compute capabilities available if you do everything in software.
    20 of 23 original engines are available for tweaking and patching via the UI.
    A couple of engines use a bit more co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
    [dsp.py, lib.rs, main.rs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]
2024-11-25 tiliqua/i2c: rewrite audio interface i2c state machine (#72)
    - WARN: the TOUCH IC config is no longer flashed by every bitstream. It's now assumed it was already flashed at the factory (or by a sane previous bitstream). This was removed both to save logic and to allow for pop-free bitstream switching (reflashing the touch IC sometimes resets the codec, maybe due to a power dip).
    - Split up `i2c.Peripheral` and `i2c.Streamer`, so the transaction-based I2C core can be used more easily by RTL directly.
    - Rewrite the old `eurorack-pmod` state machine in Amaranth based on this new interface.
    - This is used for codec, touch init, jack reading, etc
    - Resource usage is almost the same as it us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
    [eurorack_pmod.py, eurorack_pmod_peripheral.py, i2c.py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]
2024-11-25 cli: fix video timings error message
    [cli.py]
2024-11-27 bootloader: fix reconfig mute delay
    [main.rs]
2024-12-14 bootloader/polysyn: add help pages and detailed bitstream manifest (#73)
    * Increase bitstream manifest type, now includes summary and video support. Draw in bootloader.
    * Add support for help page and use this in `polysyn` bitstream
    * Fix bug where white would fade out to incorrect hue
    [dsp.py, main.rs, tiliqua_soc.py]
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
